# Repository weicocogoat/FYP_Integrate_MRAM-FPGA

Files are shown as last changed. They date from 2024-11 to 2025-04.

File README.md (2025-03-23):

# Integrating Off-Chip rapid non-volatile with RISC-V Core on FPGA
This repository documents my progress of my FYP at NTU, designing an MRAM memory controller and integrating it with the ECS-DOT SoC developed at NTU by the ECS Group.

## Navigation
If you are here from the report, please look into the FYP_Report folder for the relevant files

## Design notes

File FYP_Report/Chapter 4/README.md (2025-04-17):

# Chapter 4 - Hardware Design
Folders will namely contain the Verilog files used. 

## Section 4.1 - SPS Module
- Relevant Folder: SPS_Module
- Top Module: MRAM_Top_Module.v
- Testbench: MRAM_Top_Module_tb.v

## Section 4.2 - SPS with burst functionality
- Relevant Folder: SPS_Burst
- Top Module: Integrate_Top_Module.v
- Testbench: Integrate_Top_Module_tb.v
- Constraint file is for the Tang Nano 9k

## Section 4.3 - SPI-SPS Module
- Relevant Folder: SPI-SPS
- Top Module: SPI_Top_Module.v
- Testbench: SPI_Top_Module_tb.v

## Section 4.4 - SPI Module
- Relevant Folder: SPI_Module
- Top Module: SPI_top_module.v
- Testbench: SPI_Slave_tb.v
- Contraint file is for the Tang Nano 9k

## Section 4.5.1 - Initial I2C Module
- Relevant Folder: I2C_Initial_Design
- Top Module: top_module.v
- Testbench: top_module_tb.v

## Section 4.5.2 - OpenIP Cores I2C Slave
- Relevant Folder: ip-core-communication-controller_i2c_slave/rtl
- Top Module: i2cSlaveTop.v
- Testbench: ip-core-communication-controller_i2c_slave/sim & ip-core-communication-controller_i2c_slave/bench
- Running the testbench requires Icarus Verilog and GTK wave

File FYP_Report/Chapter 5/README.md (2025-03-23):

## Section 5.1 - SPS burst module
- Includes the STM32 C file and .ioc file that is used to test the SPS burst design
- Also includes the PulseView waveforms of the operations performed in the [video](https://youtu.be/q7COcFoSyC0) showcasing SPS burst operations

## Section 5.2 - SPI Module
- Includes the full Gowin IDE files generated for the Simple_SPI and Truncated_SPI implementations
- Includes the RPI Pico files and several PulseView waveforms

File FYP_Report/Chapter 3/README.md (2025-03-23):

# Chapter 3 - Hardware and their relevant software
This README will go over the hardware utilized and the corresponding software used.

## Section 3.2 PCB Designs

### Passive PCB Design
- PCB design 1 files, done in KiCad 8.0
### TangNano-MRAM zip file
- PCB design 2 files, done in KiCad 8.0
- This is the most relevant and up-to-date PCB design that is being used

## Section 3.3 FPGA
- For Zedboard, Vivado and Vitis were used
- For Tang Nano FPGA, the [Gowin IDE](https://www.gowinsemi.com/en/support/download_eda/) was used

## Section 3.4 MCUs
- For STM32, STM32CubeIDE was utilized
- For Raspberry Pi, the Raspberry Pi OS (64-bit) was used
- For ESP32, the Arduino IDE was used
- For Raspberry Pi Pico 2w, Thonny and micropython was used

## Section 3.5 Logic Analyzer
- For the Salae Logic Analyzer, [PulseView](https://sigrok.org/wiki/Downloads) was used

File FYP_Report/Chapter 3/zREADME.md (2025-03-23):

## Passive PCB Design
- PCB design 1 files, done in KiCad

## TangNano-MRAM zip file
- PCB design 2 files, done in KiCad

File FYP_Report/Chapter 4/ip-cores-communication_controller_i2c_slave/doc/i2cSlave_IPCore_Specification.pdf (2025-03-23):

# i2cSlave

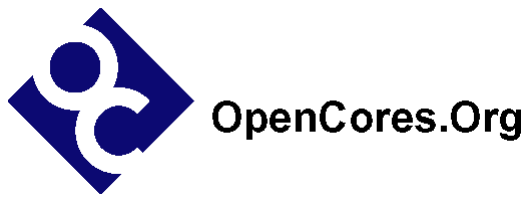
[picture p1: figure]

# Specification

### Author: Steve Fielding sfielding@base2designs.com

### Rev. 1.1 December 17, 2008

OpenCores | 12/17/2008

### Revision History

Rev. | Date | Author | Description
1.0 | 11/07/08 | Sfielding | Created
1.1 | 12/17/08 | Sfielding | Added Aardvark software chapter
www.opencores.org | Rev 1.1 | ii

# Contents

www.opencores.org | Rev 1.1 | iii

1

# Introduction

i2cSlave is a minimalist I2C slave IP core that provides the basic framework for the implementation of custom I2C slave devices. The core provides a means to read and write up to 256 8-byte registers. These registers can be connected to the users custom logic, thus implementing a simple control and status interface.

www.opencores.org | Rev 1.1 | 1 of 14

2

# Architecture

3

# Operation

The core has up 256 registers that can be accessed via I2C. I2C write operations are used to set the register address pointer, and write the register data. I2C reads are used to read the register data. Successive data reads or writes result in data being read or written from incremental register addresses. There is no limit on how much data can be read or written in a single access, but the internal register address pointer will wrap round to 0 once it reaches 255. Note that the address pointer is not initialized at reset, and the address pointer must be set via I2C.
Operation is explained through the use of examples. Examples assume 4 R/W registers at address 0x0, and 4 read only registers at address 0x4, with contents = 0x12345678
Set register address pointer = 0x00:
Byte No. | Data | R/W | Description | Start/Stop | Ack/Nak
1 | 0x78 | W | Device address WR | STA
2 | 0x00 | W | Set register address = 0x00 | STO

Write 4 bytes of data starting at register address 0x00:
Byte No. | Data | R/W | Description | Start/Stop | Ack/Nak
1 | 0x78 | W | Device address WR | STA
2 | 0x00 | W | Set register address = 0x00
3 | 0x89 | W | Write reg[0x00]
4 | 0xab | W | Write reg[0x01]
5 | 0xcd | W | Write reg[0x02]
6 | 0xef | W | Write reg[0x03] | STO

Read 4 bytes of data starting at register address 0x00:
Byte No. | Data | R/W | Description | Start/Stop | Ack/Nak
1 | 0x78 | W | Device address WR | STA

2 | 0x00 | W | Set register address = 0x00 | STO
3 | 0x79 | W | Device address RD | STA
4 | 0x89 | R | Read reg[0x00] | | ACK
5 | 0xab | R | Read reg[0x01] | | ACK
6 | 0xcd | R | Read reg[0x02] | | ACK
7 | 0xef | R | Read reg[0x03] | | NAK

Read 4 bytes of data starting at register address 0x04:
Byte No. | Data | R/W | Description | Start/Stop | Ack/Nak
1 | 0x78 | W | Device address WR | STA
2 | 0x04 | W | Set register address = 0x04 | STO
3 | 0x79 | W | Device address RD | STA
4 | 0x12 | R | Read reg[0x04] | | ACK
5 | 0x34 | R | Read reg[0x05] | | ACK
6 | 0x56 | R | Read reg[0x06] | | ACK
7 | 0x78 | R | Read reg[0x07] | | NAK

## Modify the existing files

You will need to modify i2cSlave to suit your individual application. Specifically you will need to modify;
i2cSlave_define.v
Change I2C_ADDRESS to your I2C device address.
Change CLK_FREQ to match your system clock frequency.
registerInterface.v
Modify the input/output ports and the read and write processes to implement your own register interface.
i2cSlave.v
Modify the input/output ports and the instantiation of registerInterface to connect the modified registerInterface ports to the i2cSlave ports. The tri-state buffer is included here for convenience, but you may wish to remove it, and implement the tri-state buffer in your top level module. Note that only sdaIn and sdaOut are defined. If you wish for a more conventional tri-state interface, you can implement the following;
assign sda_i = sdaIn;

assign sda_o = 1'b0;
assign sda_oe_n = sdaOut;

## Add your own custom logic

Now you can include i2cSlave in your own top level module that connects the registers to your own custom logic, and connects sda and scl to your top level ports.

4.

# Aardvark I2C Test Software

The TotalPhase Aardvark I2C Host Adapter (http://www.totalphase.com/products/aardvark_i2cspi/) provides a great way to test the i2cSlave core in hardware. The Aardvark connects to the target via 3 wires (SCL, SDA, GND), and connects to a PC via USB. You can use the TotalPhase Aardvark GUI to read and write to the core.

Aardvark GUI
Connect the Aardvark to your target hardware and a PC. On the PC open the Aardvark GUI, select the Aardvark device, then select batch mode. Click the 'Load' button, and browse to sw\aardvark_xml\readWriteTest.xml and click 'Open'. Now, click on the 'Execute' button.
You should see something similar to the following:

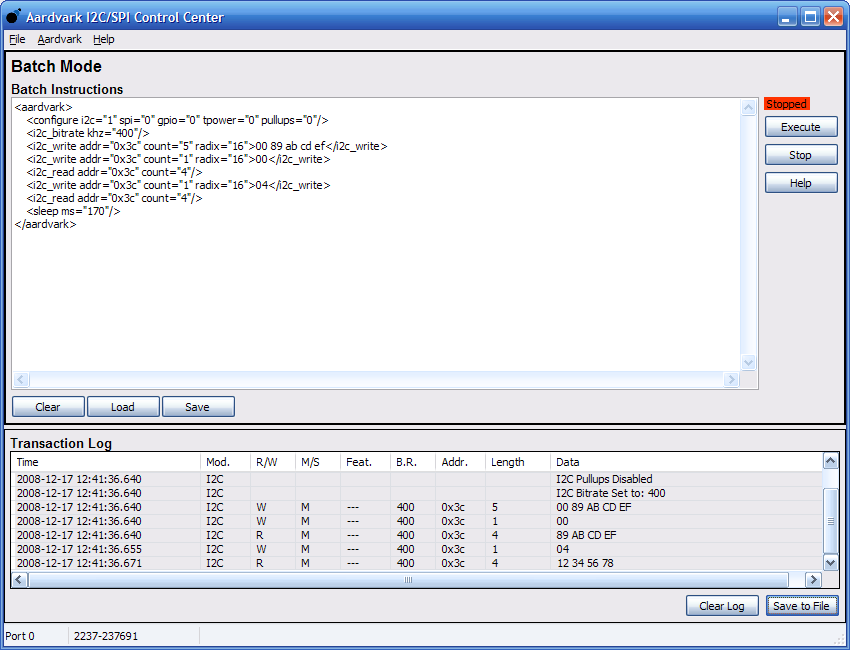
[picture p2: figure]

Aardvark C/C++ MinGW
Windows gcc-mingw32:
1) Install GCC MinGW32.
From Base2Designs CD-ROM tools\MinGW_MSYS
Or the the latest version can be downloaded from the MinGW website: http://www.mingw.org/
2) Install MSYS
From Base2Designs CD-ROM tools\MinGW_MSYS
Or the latest version can be downloaded from the MinGW website: http://www.mingw.org/
3) From i2cSlave/sw/aardvark_c type 'make' at the MSYS command line
4) The executable is in i2cSlave/sw/aardvark_c/_output/

5

# Clocks

Name | Source | Rates (MHz) | Remarks | Description
Max | Min | Res
clk | Input Pad | Limited by hardware | TBD. Only tested at 48MHz | - Duty cycle | 50/50. | System clock.

Table 1: List of clocks

6

# IO Ports

Port | Width | Direction | Description
clk | 1 | input | Clock. If you change this clock from 48MHz you may need to alter some constants in the i2cSlave_define.v file
rst | 1 | input | 1 = reset. Synchronous to clk. Resets all logic.
sda | 8 | inout | I2C SDA
scl | 8 | inout | I2C SCL
MyReg[3:0] | 8 | output | I2C accessible output registers. Modify to implement your own custom outputs
MyReg[7:4] | 8 | input | I2C accessible input registers. Modify to implement your own custom inputs

Table 2: List of IO ports

7

# Resource Utilization

Target Device | Logic Cells / Macrocells | Memory bits
EPM7256 (256 macrocell CPLD) | 143 macrocells | 0
EP2C20 | 218 logic cells | 0

Table 3 Resource utilization for Altera CycloneEP2C20, and EPM7256

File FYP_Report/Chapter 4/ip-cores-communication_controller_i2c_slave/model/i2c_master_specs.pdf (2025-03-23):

I

2

# C-Master Core Specification

# Author: Richard Herveille

### rherveille@opencores.org

### Rev. 0.9 July 3, 2003

## This page has been intentionally left blank

### Revision History

Rev. | Date | Author | Description
0.1 | 17/02/01 | Richard Herveille | First draft release
0.2 | 01/03/01 | Richard Herveille | Some cleaning up throughout the document Added ‘Programming Examples’ section
0.3 | | Richard Herveille | Added some comments after core-changes - added BUSY bit (status register) - changed I2C IO for ASIC support - added comment for FGPA IO
0.4 | 10/19/01 | Richard Herveille | Changed core’s databus size to 8bit. Changed documentation to reflect changes. Changed port names to new naming convention.
0.5 | 18/02/02 | Richard Herveille | Changed table headers. Added OpenCores logo.
0.5a | 05/02/02 | Richard Herveille | Reviewed entire document.
0.6 | 21/03/02 | Richard Herveille | Added Appendix A, Synthesis Results
0.7 | 25/06/02 | Richard Herveille | Changed Prescale Register formula
0.8 | 30/12/02 | Richard Herveille | Added Multi-Master capabilities. New timing diagrams.
0.9 | 03/07/03 | Richard Herveille | Changed ‘0x5C’ to ‘0xAC’ in Example1. Changed ‘RW’ to ‘W’ in Command Register. Changed ‘RW’ to ‘W’ in Transmit Register.

OpenCores | I²
C-Master core | 7/3/2003
www.opencores.org | Rev 0.8 Preliminary | 1 of 15

1

# Introduction

I

2
C is a two-wire, bi-directional serial bus that provides a simple and efficient method of data exchange between devices. It is most suitable for applications requiring occasional communication over a short distance between many devices. The I²
C standard is a true
multi-master bus including collision detection and arbitration that prevents data corruption if two or more masters attempt to control the bus simultaneously.

The interface defines 3 transmission speeds:
- Normal: 100Kbps
- Fast: 400Kbps
- High speed: 3.5Mbps

Only 100Kbps and 400Kbps modes are supported directly. For High speed special IOs are needed. If these IOs are available and used, then High speed is also supported.

## FEATURES

- Compatible with Philips I²
C standard
- Multi Master Operation
- Software programmable clock frequency
- Clock Stretching and Wait state generation
- Software programmable acknowledge bit
- Interrupt or bit-polling driven byte-by-byte data-transfers
- Arbitration lost interrupt, with automatic transfer cancelation
- Start/Stop/Repeated Start/Acknowledge generation
- Start/Stop/Repeated Start detection
- Bus busy detection
- Supports 7 and 10bit addressing mode
- Operates from a wide range of input clock frequencies
- Static synchronous design
- Fully synthesizable

2

# IO ports

## 2.1 Core Parameters

Parameter | Type | Default | Description
ARST_LVL | Bit | 1’b0 | Asynchronous reset level

### 2.1.1 ARST_LVL

The asynchronous reset level can be set to either active high (1’b1) or active low (1’b0).

## 2.2 WISHBONE interface signals

Port | Width | Direction | Description
wb_clk_i | 1 | Input | Master clock
wb_rst_i | 1 | Input | Synchronous reset, active high
arst_i | 1 | Input | Asynchronous reset
wb_adr_i | 3 | Input | Lower address bits
wb_dat_i | 8 | Input | Data towards the core
wb_dat_o | 8 | Output | Data from the core
wb_we_i | 1 | Input | Write enable input
wb_stb_i | 1 | Input | Strobe signal/Core select input
wb_cyc_i | 1 | Input | Valid bus cycle input
wb_ack_o | 1 | Output | Bus cycle acknowledge output
wb_inta_o | 1 | Output | Interrupt signal output

The core features a WISHBONE RevB.3 compliant WISHBONE Classic interface. All output signals are registered. Each access takes 2 clock cycles.
arst_i is not a WISHBONE compatible signal. It is provided for FPGA implementations. Using [arst_i] instead of [wb_rst_i] can result in lower cell-usage and higher performance, because most FPGAs provide a dedicated asynchronous reset path. Use either [arst_i] or [wb_rst_i], tie the other to a negated state.

## 2.3 External connections

Port | Width | Direction | Description
scl_pad_i | 1 | Input | Serial Clock line input
scl_pad_o | 1 | Output | Serial Clock line output
scl_pad_oe | 1 | Output | Serial Clock line output enable
sda_pad_i | 1 | Input | Serial Data line input
sda_pad_o | 1 | Output | Serial Data line output
sda_pad_oe | 1 | Output | Serial Data line output enable

The I²
C interface uses a serial data line (SDA) and a serial clock line (SCL) for data transfers. All devices connected to these two signals must have open drain or open collector outputs. Both lines must be pulled-up to VCC by external resistors.

The tri-state buffers for the SCL and SDA lines must be added at a higher hierarchical level. Connections should be made according to the following figure:

For FPGA designs the compiler can automatically insert these buffers using the following VHDL code:

scl <= scl_pad_o when (scl_padoen_oe = ‘0’) else ‘Z’;
sda <= sda_pad_o when (sda_padoen_oe = ‘0’) else ‘Z’;
scl_pad_i <= scl;
scl_pad_i <= sda;

Verilog code:

assign scl = scl_padoen_oe ? 1’bz : scl_pad_o; assign sda = sda_padoen_oe ? 1’bz: sda_pad_o; assign scl_pad_i = scl;
assign sda_pad_i = sda;

scl_pad_i

scl_pad_o

scl_padoen_o
sda_pad_i

sda_pad_o

sda_padoen_o

SCL

SDA

3

# Registers

## 3.1 Registers list

Name | Address | Width | Access | Description
PRERlo | 0x00 | 8 | RW | Clock Prescale register lo-byte
PRERhi | 0x01 | 8 | RW | Clock Prescale register hi-byte
CTR | 0x02 | 8 | RW | Control register
TXR | 0x03 | 8 | W | Transmit register
RXR | 0x03 | 8 | R | Receive register
CR | 0x04 | 8 | W | Command register
SR | 0x04 | 8 | R | Status register

## 3.2 Register description

### 3.2.1 Prescale Register

This register is used to prescale the SCL clock line. Due to the structure of the I² C
interface, the core uses a 5*SCL clock internally. The prescale register must be programmed to this 5*SCL frequency (minus 1). Change the value of the prescale register only when the ‘EN’ bit is cleared.

Example: wb_clk_i = 32MHz, desired SCL = 100KHz
1 | 63 ( | ) | 3 ( | ) 5 100
32 | dec | F hex
KHz
MHz prescale | − = | = ∗ =

Reset value: 0xFFFF

### 3.2.2 Control register

Bit # | Access | Description
7 | RW | EN, I² C core enable bit. When set to ‘1’, the core is enabled. When set to ‘0’, the core is disabled.
6 | RW | IEN, I² C core interrupt enable bit. When set to ‘1’, interrupt is enabled. When set to ‘0’, interrupt is disabled.
5:0 | RW | Reserved
Reset Value: 0x00

The core responds to new commands only when the ‘EN’ bit is set. Pending commands are finished. Clear the ‘EN’ bit only when no transfer is in progress, i.e. after a STOP command, or when the command register has the STO bit set. When halted during a transfer, the core can hang the I²
C bus.

### 3.2.3 Transmit register

Bit # | Access | Description
7:1 | W | Next byte to transmit via I² C
0 | W | In case of a data transfer this bit represent the data’s LSB. In case of a slave address transfer this bit represents the RW bit. ‘1’ = reading from slave ‘0’ = writing to slave

Reset value: 0x00

### 3.2.4 Receive register

Bit # | Access | Description
7:0 | R | Last byte received via I² C
Reset value: 0x00

### 3.2.5 Command register

Bit # | Access | Description
7 | W | STA, generate (repeated) start condition
6 | W | STO, generate stop condition
5 | W | RD, read from slave
4 | W | WR, write to slave
3 | W | ACK, when a receiver, sent ACK (ACK = ‘0’) or NACK (ACK = ‘1’)
2:1 | W | Reserved
0 | W | IACK, Interrupt acknowledge. When set, clears a pending interrupt.
Reset Value: 0x00

The STA, STO, RD, WR, and IACK bits are cleared automatically. These bits are always read as zeros.

### 3.2.6 Status register

Bit # | Access | Description
7 | R | RxACK, Received acknowledge from slave. This flag represents acknowledge from the addressed slave. ‘1’ = No acknowledge received ‘0’ = Acknowledge received
6 | R | Busy, I² C bus busy ‘1’ after START signal detected ‘0’ after STOP signal detected
5 | R | AL, Arbitration lost This bit is set when the core lost arbitration. Arbitration is lost when: • a STOP signal is detected, but non requested • The master drives SDA high, but SDA is low. See bus-arbitration section for more information.
4:2 | R | Reserved
1 | R | TIP, Transfer in progress. ‘1’ when transferring data ‘0’ when transfer complete
0 | R | IF, Interrupt Flag. This bit is set when an interrupt is pending, which will cause a processor interrupt request if the IEN bit is set. The Interrupt Flag is set when: • one byte transfer has been completed • arbitration is lost

Reset Value: 0x00

Please note that all reserved bits are read as zeros. To ensure forward compatibility, they should be written as zeros.

4

# Operation

## 4.1 System Configuration

The I²
C system uses a serial data line (SDA) and a serial clock line (SCL) for data transfers. All devices connected to these two signals must have open drain or open collector outputs. The logic AND function is exercised on both lines with external pull-up resistors.

Data is transferred between a Master and a Slave synchronously to SCL on the SDA line on a byte-by-byte basis. Each data byte is 8 bits long. There is one SCL clock pulse for each data bit with the MSB being transmitted first. An acknowledge bit follows each transferred byte. Each bit is sampled during the high period of SCL; therefore, the SDA line may be changed only during the low period of SCL and must be held stable during the high period of SCL. A transition on the SDA line while SCL is high is interpreted as a command (see START and STOP signals).

## 4.2 I² C Protocol

Normally, a standard communication consists of four parts:
1) START signal generation
2) Slave address transfer
3) Data transfer
4) STOP signal generation
S | A7 | A6 | A5 | A4 | A3 | A2 | A1 | RW ACK | D7 | D6 | D5 | D4 | D3 | D2 | D1 | D0 NACK | P

SCL

SDA

1 | 2 | 3 | 4 | 5 | 6 | 7 | 8 | 9
MSB | LSB
1 | 2 | 3 | 4 | 5 | 6 | 7 | 8 | 9
MSB | LSB

### 4.2.1 START signal

When the bus is free/idle, meaning no master device is engaging the bus (both SCL and SDA lines are high), a master can initiate a transfer by sending a START signal. A START signal, usually referred to as the S-bit, is defined as a high-to-low transition of SDA while SCL is high. The START signal denotes the beginning of a new data transfer. A Repeated START is a START signal without first generating a STOP signal. The master uses this method to communicate with another slave or the same slave in a different transfer direction (e.g. from writing to a device to reading from a device) without releasing the bus.

The core generates a START signal when the STA-bit in the Command Register is set and the RD or WR bits are set. Depending on the current status of the SCL line, a START or Repeated START is generated.

### 4.2.2 Slave Address Transfer

The first byte of data transferred by the master immediately after the START signal is the slave address. This is a seven-bits calling address followed by a RW bit. The RW bit signals the slave the data transfer direction. No two slaves in the system can have the same address. Only the slave with an address that matches the one transmitted by the master will respond by returning an acknowledge bit by pulling the SDA low at the 9th SCL clock cycle.

Note: The core supports 10bit slave addresses by generating two address transfers. See the Philips I²
C specifications for more details.

The core treats a Slave Address Transfer as any other write action. Store the slave device’s address in the Transmit Register and set the WR bit. The core will then transfer the slave address on the bus.

### 4.2.3 Data Transfer

Once successful slave addressing has been achieved, the data transfer can proceed on a byte-by-byte basis in the direction specified by the RW bit sent by the master. Each transferred byte is followed by an acknowledge bit on the 9th SCL clock cycle. If the slave signals a No Acknowledge, the master can generate a STOP signal to abort the data transfer or generate a Repeated START signal and start a new transfer cycle.

If the master, as the receiving device, does not acknowledge the slave, the slave releases the SDA line for the master to generate a STOP or Repeated START signal.

To write data to a slave, store the data to be transmitted in the Transmit Register and set the WR bit. To read data from a slave, set the RD bit. During a transfer the core set the TIP flag, indicating that a Transfer is In Progress. When the transfer is done the TIP flag is reset, the IF flag set and, when enabled, an interrupt generated. The Receive Register contains valid data after the IF flag has been set. The user may issue a new write or read command when the TIP flag is reset.

### 4.2.4 STOP signal

The master can terminate the communication by generating a STOP signal. A STOP signal, usually referred to as the P-bit, is defined as a low-to-high transition of SDA while SCL is at logical ‘1’.

## 4.3 Arbitration Procedure

### 4.3.1 Clock Synchronization

The I²
C bus is a true multimaster bus that allows more than one master to be connected on it. If two or more masters simultaneously try to control the bus, a clock synchronization procedure determines the bus clock. Because of the wired-AND connection of the I²
C signals a high to low transition affects all devices connected to the bus. Therefore a high to low transition on the SCL line causes all concerned devices to count off their low period. Once a device clock has gone low it will hold the SCL line in that state until the clock high state is reached. Due to the wired-AND connection the SCL line will therefore be held low by the device with the longest low period, and held high by the device with the shortest high period.

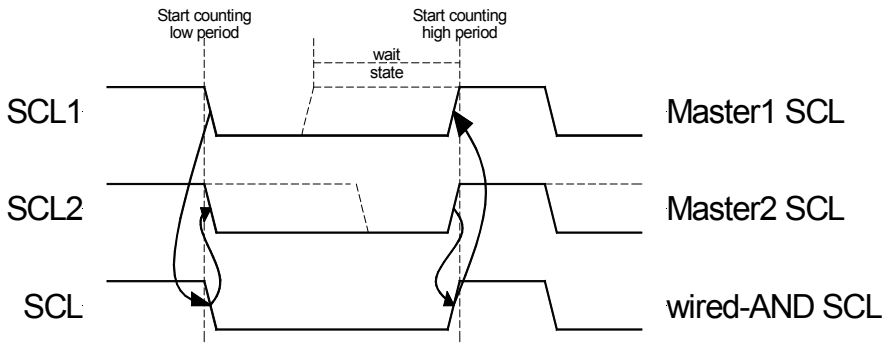
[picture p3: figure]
Start counting low period; wait state; Start counting high period; SCL1; SCL2; SCL; Master1 SCL; Master2 SCL; wired-AND SCL

### 4.3.2 Clock Stretching

Slave devices can use the clock synchronization mechanism to slow down the transfer bit rate. After the master has driven SCL low, the slave can drive SCL low for the required period and then release it. If the slave’s SCL low period is greater than the master’s SCL low period, the resulting SCL bus signal low period is stretched, thus inserting wait-states.

5

# Architecture

The I2C core is built around four primary blocks; the Clock Generator, the Byte Command Controller, the Bit Command Controller and the DataIO Shift Register. All other blocks are used for interfacing or for storing temporary values.

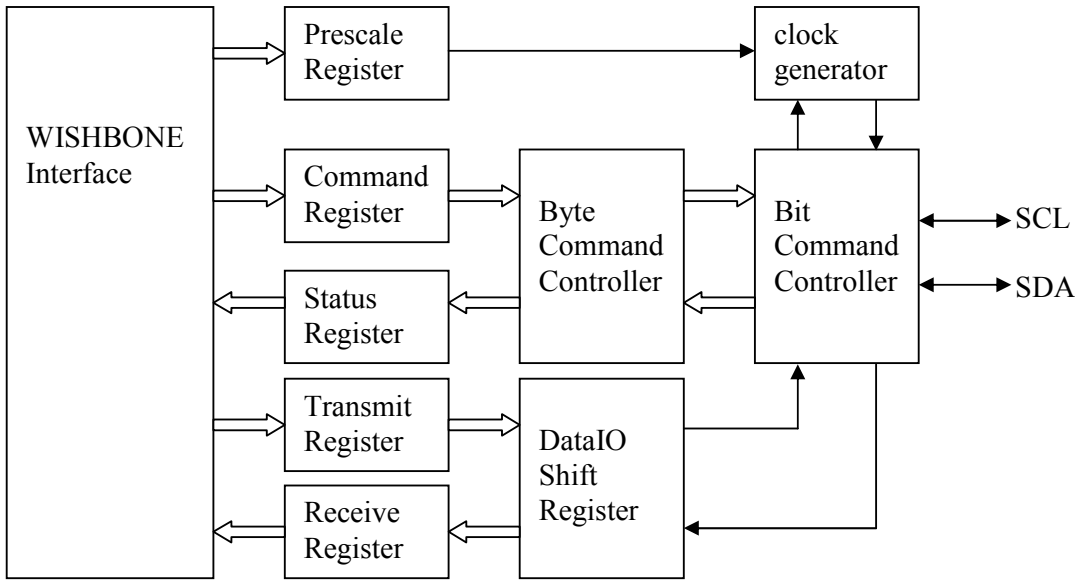
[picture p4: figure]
SCL; SDA; Prescale Register; clock generator; Command Register; Status Register; Byte Command Controller; Bit Command Controller; WISHBONE Interface; Transmit Register; Receive Register; DataIO Shift Register

## 5.1 Clock Generator

The Clock Generator generates an internal 4*Fscl clock enable signal that triggers all synchronous elements in the Bit Command Controller. It also handles clock stretching needed by some slaves.

## 5.2 Byte Command Controller

The Byte Command Controller handles I2C traffic at the byte level. It takes data from the Command Register and translates it into sequences based on the transmission of a single byte. By setting the START, STOP, and READ bit in the Command Register, for example, the Byte Command Controller generates a sequence that results in the

Fig. 5.1 Internal structure I2C Master Core

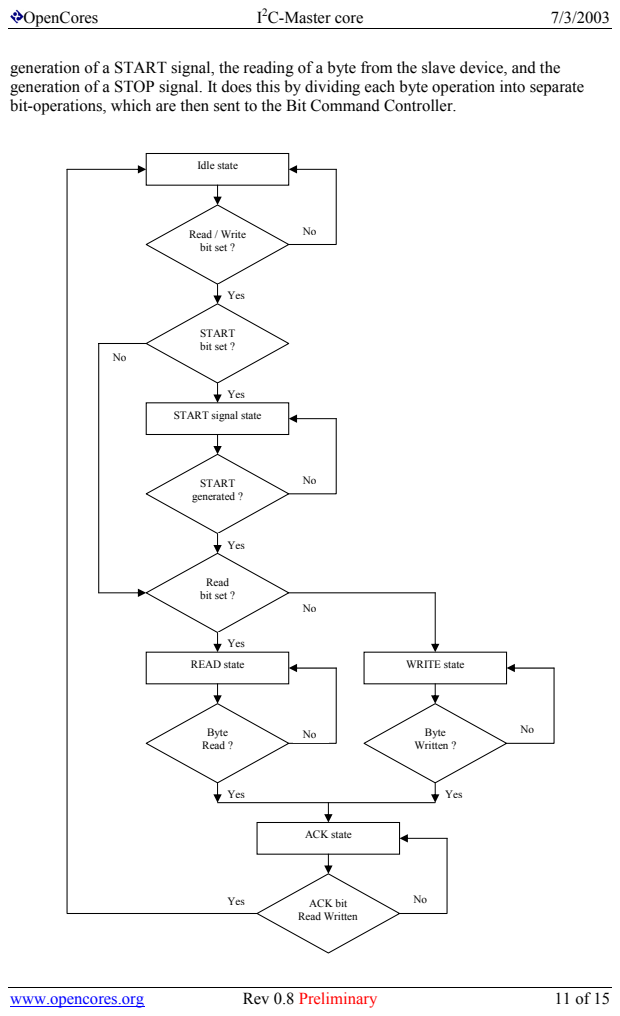
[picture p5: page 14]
Idle state; Read / Write bit set ?; Yes; START bit set ?; Read bit set ?; READ state; Byte Read ?; ACK state; WRITE state; Byte Written ?; ACK bit Read Written

generation of a START signal, the reading of a byte from the slave device, and the
generation of a STOP signal. It does this by dividing each byte operation into separate
bit-operations, which are then sent to the Bit Command Controller.

START signal state

START generated ?

## 5.3 Bit Command Controller

The Bit Command Controller handles the actual transmission of data and the generation of the specific levels for START, Repeated START, and STOP signals by controlling the SCL and SDA lines. The Byte Command Controller tells the Bit Command Controller which operation has to be performed. For a single byte read, the Bit Command Controller receives 8 separate read commands. Each bit-operation is divided into 5 pieces (idle and A, B, C, and D), except for a STOP operation which is divided into 4 pieces (idle and A, B, and C).

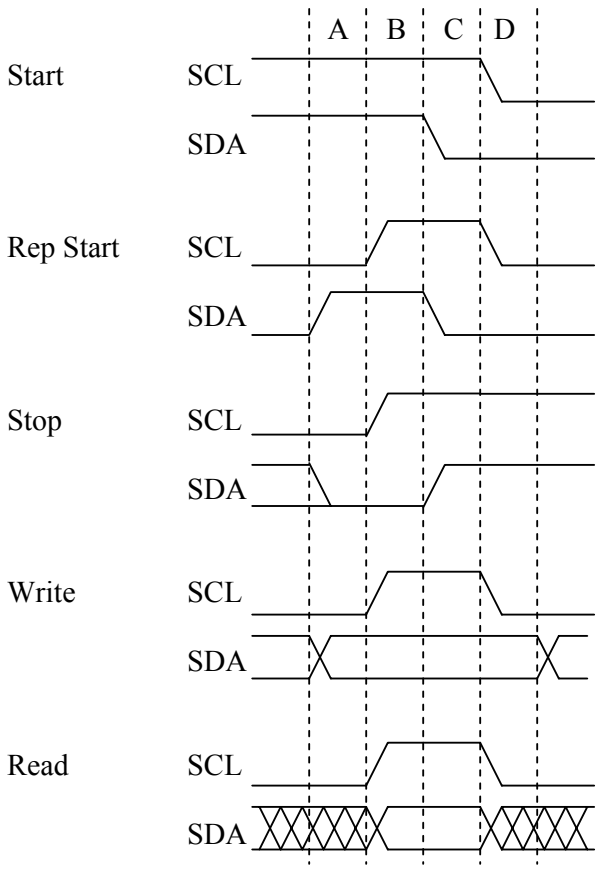
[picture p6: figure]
Start; SCL; SDA; Rep Start; Stop; Write; Read

## 5.4 DataIO Shift Register

The DataIO Shift Register contains the data associated with the current transfer. During a read action, data is shifted in from the SDA line. After a byte has been read the contents are copied into the Receive Register. During a write action, the Transmit Register’s contents are copied into the DataIO Shift Register and are then transmitted onto the SDA line.

6

# Programming examples

## Example 1

Write 1 byte of data to a slave.

Slave address = 0x51 (b”1010001”) Data to write = 0xAC

I2C Sequence:
1) generate start command
2) write slave address + write bit
3) receive acknowledge from slave
4) write data
5) receive acknowledge from slave
6) generate stop command

Commands:
1) write 0xA2 (address + write bit) to Transmit Register, set STA bit, set WR bit. -- wait for interrupt or TIP flag to negate --
2) read RxACK bit from Status Register, should be ‘0’.
write 0xAC to Transmit register, set STO bit, set WR bit.
-- wait for interrupt or TIP flag to negate --
3) read RxACK bit from Status Register, should be ‘0’.

Please note that the time for the Interrupt Service Routine is not shown here. It is assumed that the ISR is much faster then the I²
C cycle time, and therefore not visible.

## Example 2

Read a byte of data from an I2C memory device.

Slave address = 0x4E
Memory location to read from = 0x20

I2C sequence:
1) generate start signal
2) write slave address + write bit
3) receive acknowledge from slave
4) write memory location
5) receive acknowledge from slave
6) generate repeated start signal
7) write slave address + read bit
8) receive acknowledge from slave
9) read byte from slave
10) write no acknowledge (NACK) to slave, indicating end of transfer
11) generate stop signal

Commands:
1) write 0x9C (address + write bit) to Transmit Register, set STA bit, set WR bit. -- wait for interrupt or TIP flag to negate --
2) read RxACK bit from Status Register, should be ‘0’.
write 0x20 to Transmit register, set WR bit.
-- wait for interrupt or TIP flag to negate --
3) read RxACK bit from Status Register, should be ‘0’.
write 0x9D (address + read bit) to Transmit Register, set STA bit, set WR bit. -- wait for interrupt or TIP flag to negate --
4) set RD bit, set ACK to ‘1’ (NACK), set STO bit

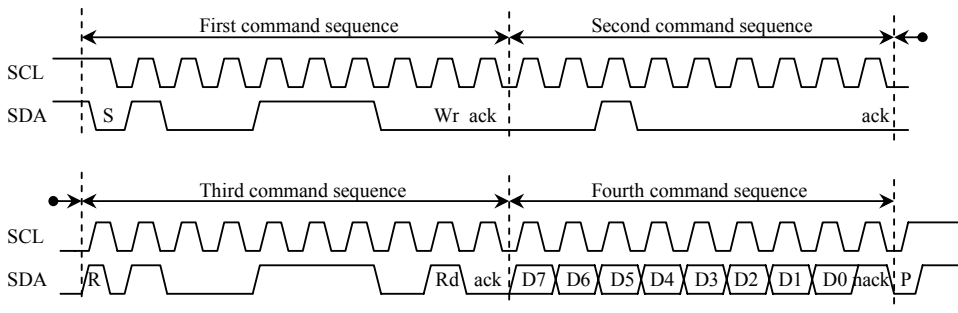
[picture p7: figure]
First command sequence; Second command sequence; SDA; Wr ack; ack; SCL; Third command sequence; Fourth command sequence

Please note that the time for the Interrupt Service Routine is not shown here. It is assumed that the ISR is much faster then the I²
C cycle time, and therefore not visible.
SDA | R | Rd ack | D7 D6 D5 D4 D3 D2 D1 D0 nack | P

# Appendix A

# Synthesis results

Synthesis tool: Synplify Pro

Technology | Device | Speed grade | Fmax | Resource usage
ACTEL | A54SX16ATQ100 | std | 58MHz | Modules: 352
Altera | EP10K50ETC144 | -3 | 82MHz | LCs: 294
| EP20K30ETC144 | -3 | 74MHz | ATOMS: 257
Xilinx | 2s15CS144 | -5 | 82MHz | LUTs: 229
| XCV50ECS144 | -8 | 118MHz | LUTs: 230

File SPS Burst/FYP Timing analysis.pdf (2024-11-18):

# Timing analysis

## Integrated Overview of Controller

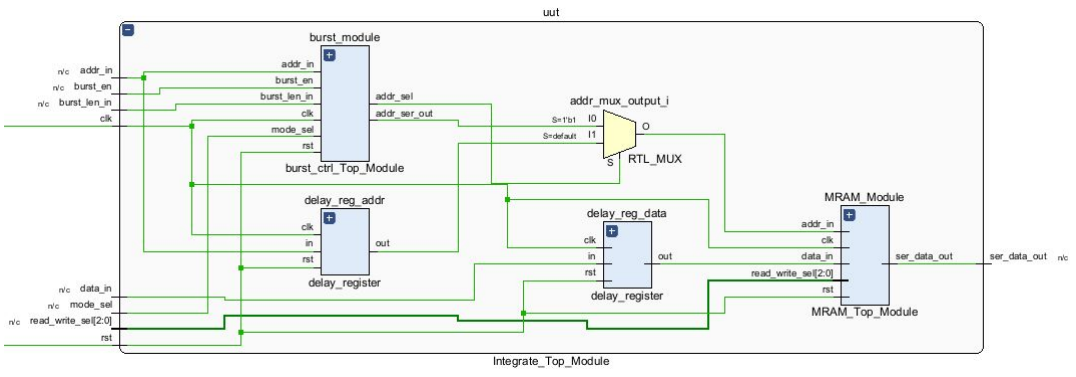
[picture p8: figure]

## During Single Transfer / First loop of Burst Transfer

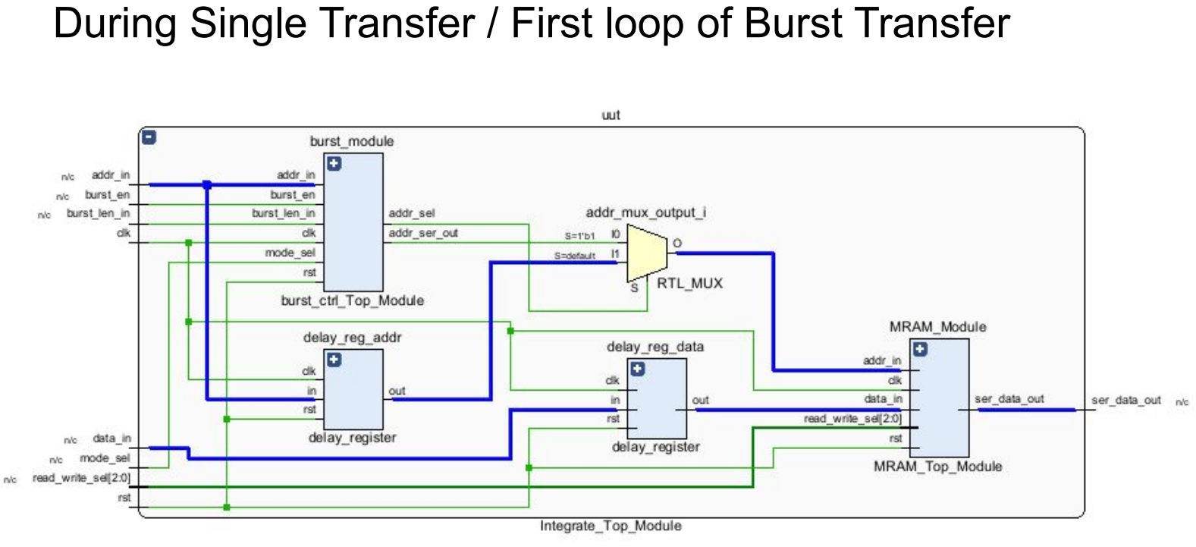
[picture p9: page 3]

## During Burst Transfer

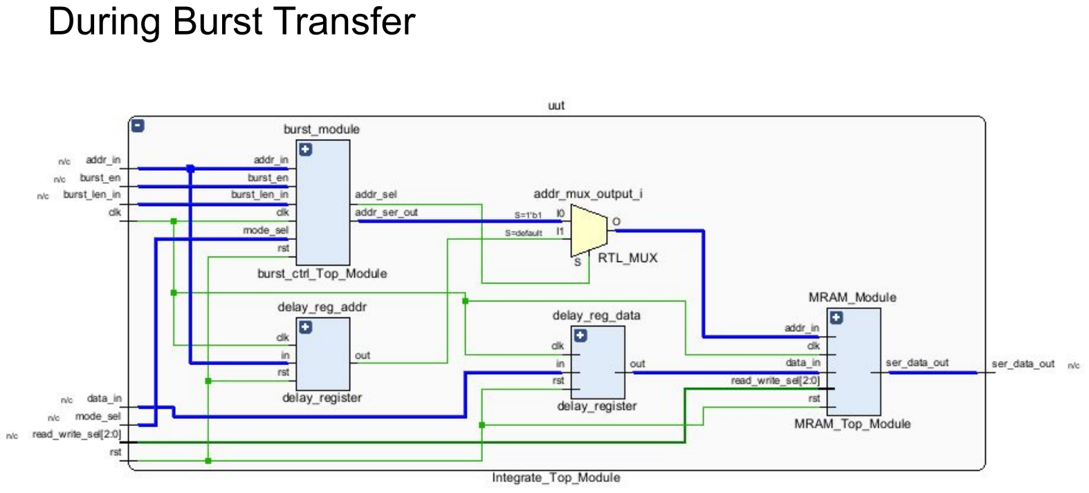
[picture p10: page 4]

## Burst Module

If Single Transfer is selected, don’t do anything.

Done through setting the mux to 0.

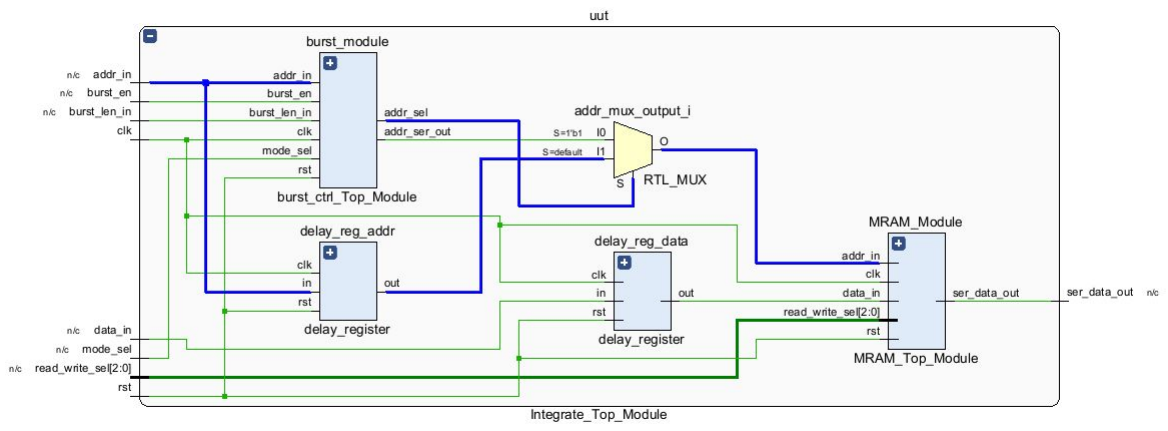
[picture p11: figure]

## Burst Module - Burst len

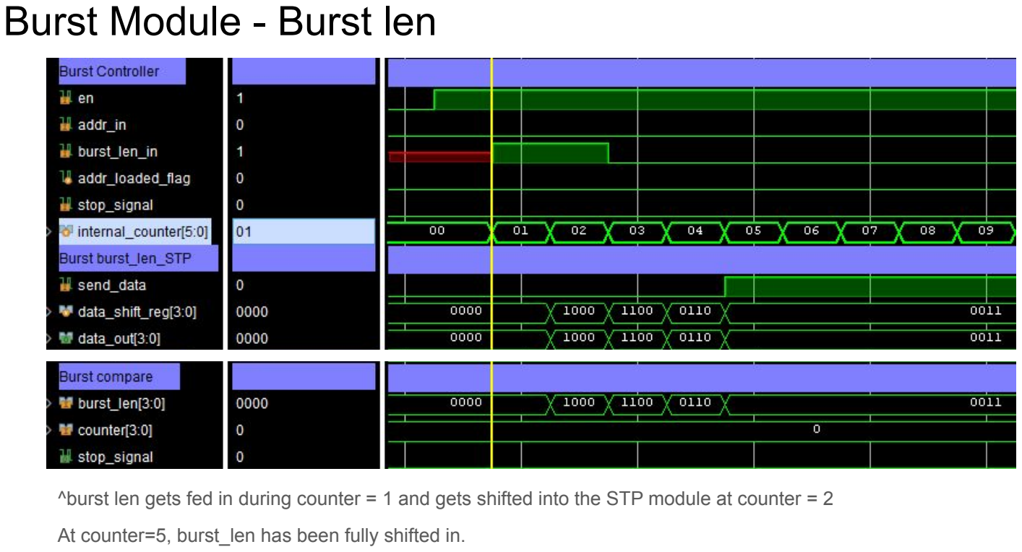
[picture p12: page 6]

^burst len gets fed in during counter = 1 and gets shifted into the STP module at counter = 2

At counter=5, burst_len has been fully shifted in.

## Burst Module - Initial addr

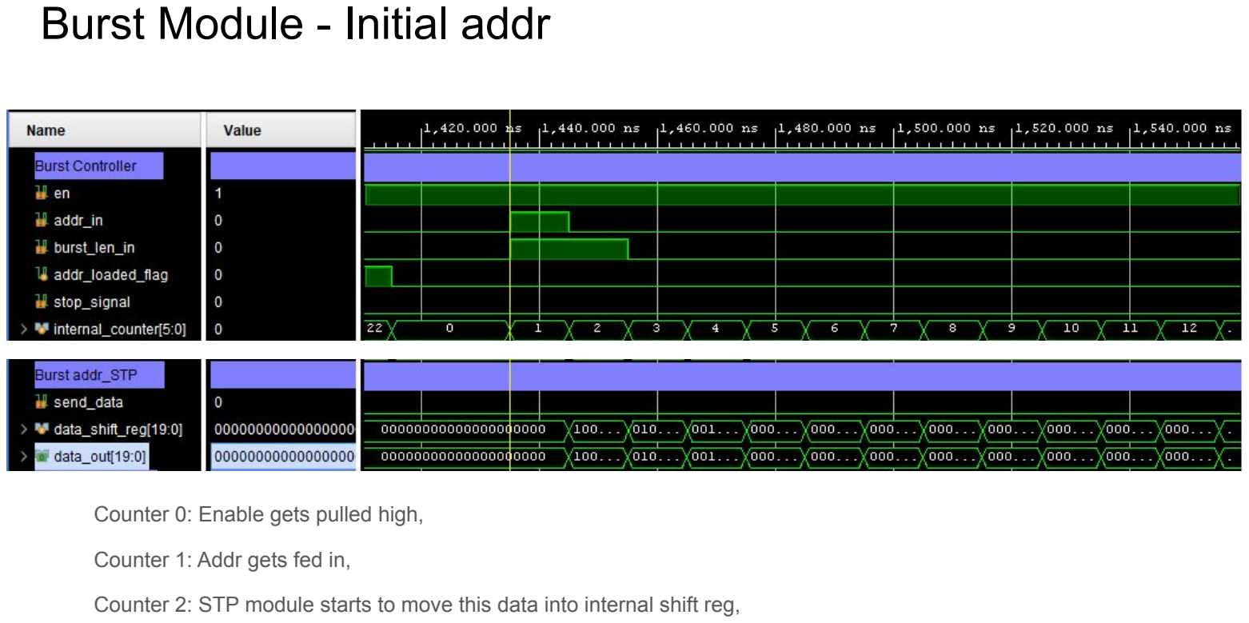
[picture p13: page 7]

Counter 0: Enable gets pulled high,

Counter 1: Addr gets fed in,

Counter 2: STP module starts to move this data into internal shift reg,

## Burst Module - Initial addr

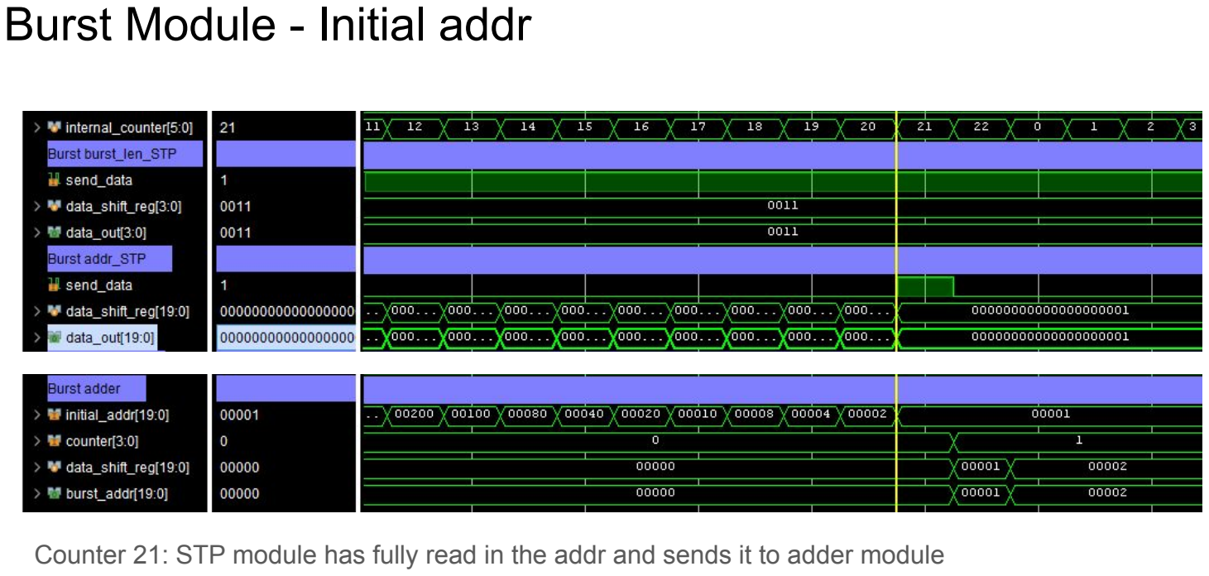
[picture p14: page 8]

Counter 21: STP module has fully read in the addr and sends it to adder module

## Burst Module - Initial addr

After initial addr is loaded, set the loaded flag and addr_sel(mux control)

Addr read for the STP/PTS module starts when counter = 2

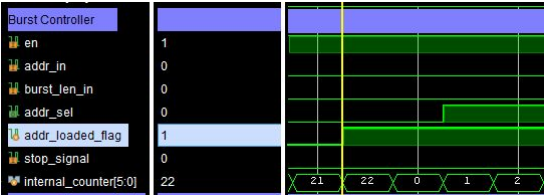
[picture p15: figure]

## Burst Module - Adder

Takes initial addr and counter module’s value and adds them tgt

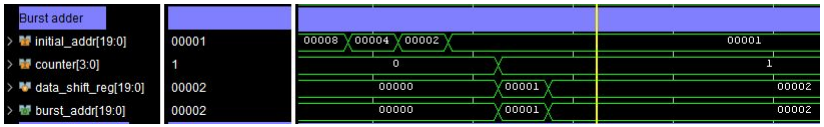
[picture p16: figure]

Counter 22: Initial addr and counter are both available in the adder module

Counter 0 of next loop: Adds initial address and counter value together

## Burst Module - compare module

Cycle 22: When compare module detects that the counter value exceeds the burst len, assert stop signal to the burst control to stop sending address serially

## Burst Module - address PTS module

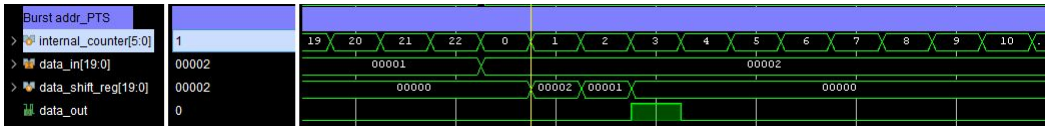
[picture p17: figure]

Counter 1: Next address to be accessed is loaded into the internal shift register

Counter 2: Starts to output the address serially. Address to be output here is 2 (from LSB to MSB)
- Counter 2: output bit 0
- Counter 3: output bit 1
- Counter 4 onwards: output bit 0
- Overall: 20’b0000_0000_0000_0000_0010

## MRAM STP/PTS module -

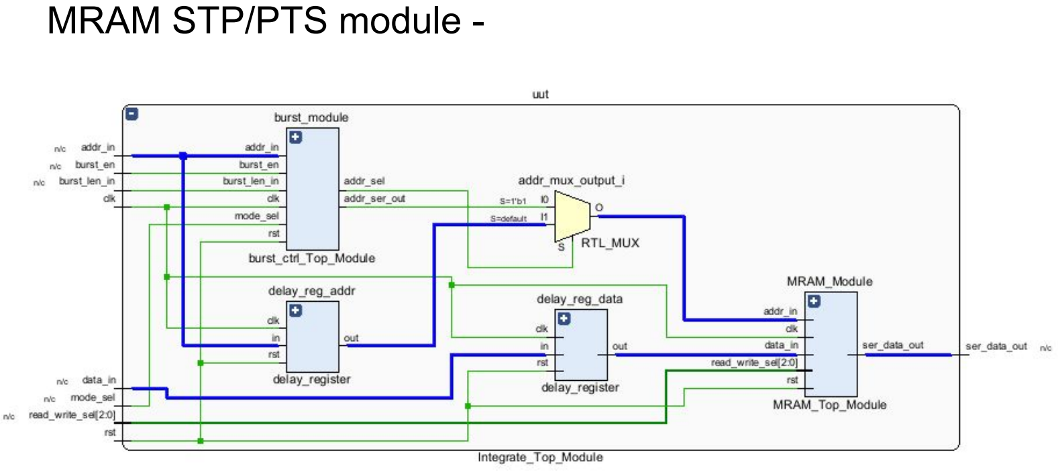
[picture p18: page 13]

## MRAM STP/PTS module - data/addr STP module (write op)

At counter = 2, data gets read and takes 1 cycle to be shifted into the internal shift register

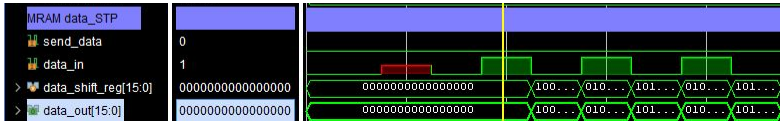
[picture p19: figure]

## MRAM STP/PTS module - data/addr STP module (write op)

At counter = 18, data is fully in the internal shift register.

At counter = 22, addr is fully in the internal shift register.

Can be sent to the MRAM alongside the control signals

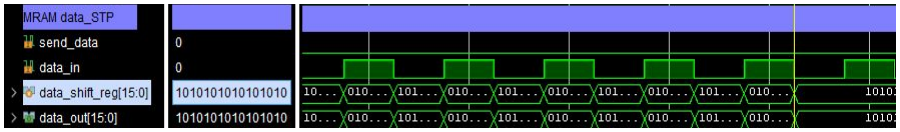
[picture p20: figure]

## MRAM STP/PTS module - addr STP module (write op)

At counter = 22, signals are asserted to write to the MRAM

At counter = 0 of the next cycle, it is in the MRAM

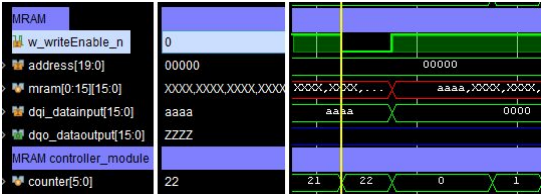
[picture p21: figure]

## MRAM STP/PTS module - Read operation

Data is read out in the next loop after address is provided

Addr = 0; data in address 0 is 5555h, 0101_0101_0101_0101b. Data is output from LSB to MSB

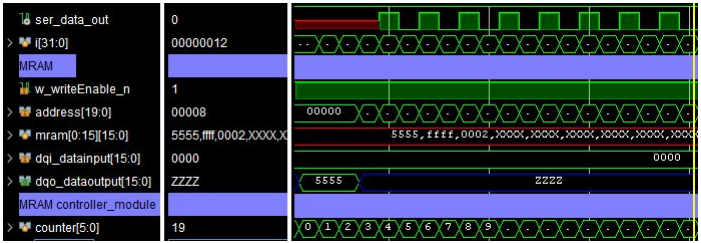
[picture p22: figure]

## Testbench - burst read example

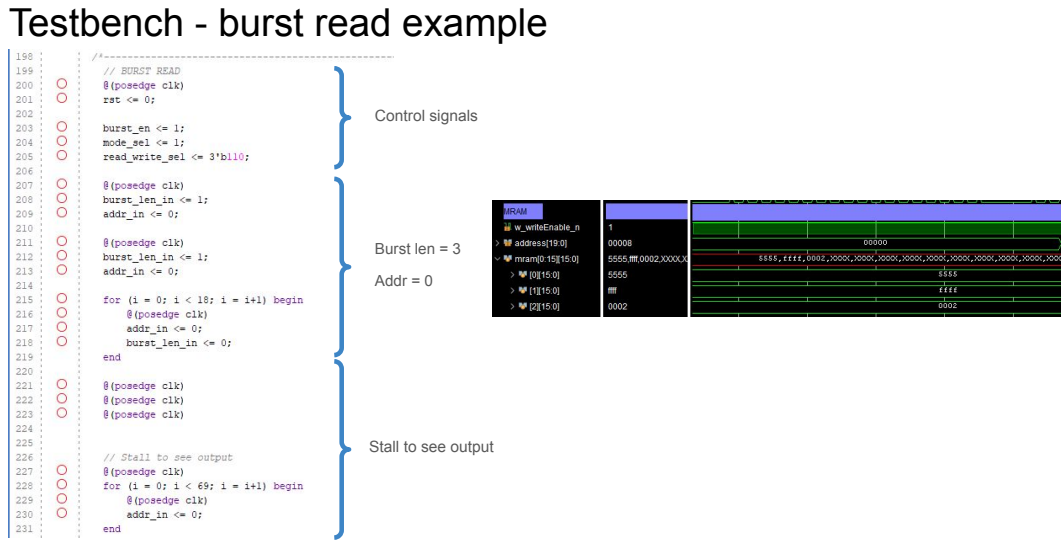
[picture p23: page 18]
Burst len = 3; Addr = 0; Control signals

Stall to see output

## Testbench - burst read example

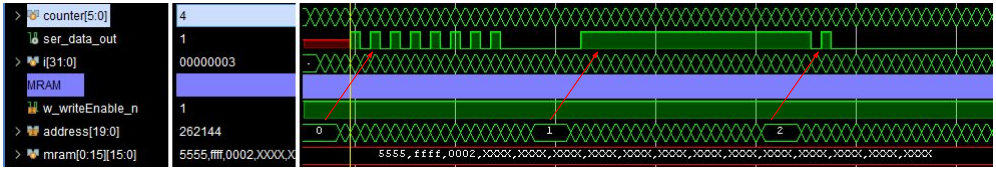
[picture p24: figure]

## Integrated module summary

1 loop consists of 23 cycles (0-22)

Writing:

- Takes 23 cycles

Reading:

- Takes 23 cycles to provide address
- Data is output on the next loop, cycle 4 to 19

## MRAM STP/PTS module standalone

Data is being shifted into the STP module’s shift register during counter 1 instead of counter 2 as opposed to the integrated module


^addr and data is being shifted into the STP modules from counter=1 onwards

## MRAM STP/PTS module standalone

MRAM is being written to on cycle 0 of the next loop

Therefore, writing takes 22 cycles (1 faster than the integrated module


^addr is fully inside the shift register at counter = 21.

## MRAM STP/PTS module standalone

Reading of data:

- Address needs to be provided first. Therefore, initial 21 cycles needed
- In the next loop, data gets serialy output from counter 3 onwards


^Data gets loaded in at counter = 2, shifted out at counter = 3

## MRAM STP/PTS module standalone

Reading of data:

- Subsequent reads in succession will case the loop to take 23 cycles due to shifting of data


^half word read, lower byte

## MRAM STP/PTS module standalone Summary

Writing:

- 22 cycles

Reading:

- Initial 22 cycles for writing address
- Subsequent 23 cycle per loop (due to shifting of data into registers I believe)
- Data is output on the next loop, cycle 3 to 18

## Questions n stuff

- Can I clarify, how does my memory controller fit into the PULP microprocessor? Does it act something like a shared memory between the PULP and accelerator that Yan Rui(the other FYP student) is developing?
- How can I request for the Zboard FPGA? Do I have to email Jeremiah for it?
- I only managed to finish this integration as there were quite a bit of bugs and synchronization issues between the 2 modules. I will continue to work on the other design I have in mind over the next few weeks.

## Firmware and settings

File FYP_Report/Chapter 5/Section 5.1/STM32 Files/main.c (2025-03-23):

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
/* Includes ------------------------------------------------------------------*/
#include "main.h"

TIM_HandleTypeDef htim1;
TIM_HandleTypeDef htim2;

UART_HandleTypeDef huart2;

void SystemClock_Config(void);
static void MX_GPIO_Init(void);
static void MX_USART2_UART_Init(void);
static void MX_TIM1_Init(void);
static void MX_TIM2_Init(void);
/**
  * @brief  The application entry point.
  * @retval int
  */
int main(void)
{
  /* MCU Configuration--------------------------------------------------------*/

  /* Reset of all peripherals, Initializes the Flash interface and the Systick. */
  HAL_Init();

  /* Configure the system clock */
  SystemClock_Config();

  /* Initialize all configured peripherals */
  MX_GPIO_Init();
  MX_USART2_UART_Init();
  MX_TIM1_Init();
  MX_TIM2_Init();
  /* USER CODE BEGIN 2 */
  	// Measuring Elapsed time
    uint32_t start, stop, elapsed;
    double elapsed_time;

	// Printing to terminal
	uint8_t tx_buff[64];
	int read_data[16];

	sprintf(tx_buff, "Starting Program\r\n");
	HAL_UART_Transmit(&huart2, tx_buff, 19, 1000);

	// Delay function
	HAL_TIM_Base_Start(&htim1);
	void delay_us (uint16_t us)
	{
	// Changes depending on prescaler set in TIM1.
	// TIM1 is connected to APB2 and will be clocked at 84Mhz
	// Possible to tweak the prescalar in order to change the clock speed
    // As of now, the prescaler is set to 1, meaning that the period is 1/84^6, approx 12ns.
	__HAL_TIM_SET_COUNTER(&htim1,0);  // set the counter value a 0
	while (__HAL_TIM_GET_COUNTER(&htim1) < us);  // wait for the counter to reach the us input in the parameter
	}

	// System reset. Ends with clock being low. 9 8 6 5
	void MRAM_reset(){
	  HAL_GPIO_WritePin(GPIOC, clk_Pin, 0);				// PC9
	  HAL_GPIO_WritePin(GPIOC, rst_Pin, 1);				// PC8
	  HAL_GPIO_WritePin(GPIOB, burst_en_Pin, 0);		// PB8
	  HAL_GPIO_WritePin(GPIOC, mode_sel_Pin, 0);		// PC6
	  HAL_GPIO_WritePin(GPIOB, burst_len_in_Pin, 0);	// PB9
	  HAL_GPIO_WritePin(GPIOC, addr_in_Pin, 0);			// PC5
	  HAL_GPIO_WritePin(GPIOA, data_in_Pin, 0);			// PA6
	  HAL_GPIO_WritePin(GPIOA, rws_0_Pin, 1);			// PA11
	  HAL_GPIO_WritePin(GPIOA, rws_1_Pin, 1);			// PA7
	  HAL_GPIO_WritePin(GPIOB, rws_2_Pin, 1);			// PB12
	  delay_us(1);
	  HAL_GPIO_WritePin(GPIOC, clk_Pin, 1);
	  delay_us(1);
	  HAL_GPIO_WritePin(GPIOC, clk_Pin, 0);
	}

	void MRAM_reset_no_HAL(){
		  // Set the GPIO pins
		  GPIOA->BSRR = 0x000008C0;
		  GPIOB->BSRR = 0x00001300;
		  GPIOC->BSRR = 0x00000360;

		  // Write the following values to the pins (as per MRAM_reset)
		  GPIOA->ODR = 0x00000880;
		  GPIOB->ODR = 0x00001000;
		  GPIOC->ODR = 0x00000100;
		  delay_us(1);
		  // Set clock high
		  GPIOC->ODR = 0x00000300;
		  delay_us(1);
		  // Set clock low
		  GPIOC->ODR = 0x00000100;
	}

	// Single word write
	uint32_t bitwise_one = 1;

	void MRAM_single_word_write(uint32_t addr_in, uint32_t data_in){		// 16-bit unsigned short
	  int  i;
	  uint32_t addr = addr_in;
	  uint32_t data = data_in;


	  for (i = 0; i < 23; i++){
		  HAL_GPIO_WritePin(GPIOC, clk_Pin, 0);					// PC9
		  HAL_GPIO_WritePin(GPIOC, rst_Pin, 0);					// PC8

		  if (i == 0){
			  HAL_GPIO_WritePin(GPIOB, burst_en_Pin, 0);		// PB8
			  HAL_GPIO_WritePin(GPIOC, mode_sel_Pin, 0);		// PC6
			  HAL_GPIO_WritePin(GPIOB, burst_len_in_Pin, 0);	// PB9
			  HAL_GPIO_WritePin(GPIOA, rws_0_Pin, 1);			// PA11
			  HAL_GPIO_WritePin(GPIOA, rws_1_Pin, 1);			// PA7
			  HAL_GPIO_WritePin(GPIOB, rws_2_Pin, 1);			// PB12
		  }
		  else{
			  if (i > 1){
				  addr = addr >> 1;
				  data = data >> 1;
			  }
			  HAL_GPIO_WritePin(GPIOC, addr_in_Pin, addr & bitwise_one);		// PC5
			  HAL_GPIO_WritePin(GPIOA, data_in_Pin, data & bitwise_one);		// PA6
		  }

		  //delay_us(1);
		  HAL_GPIO_WritePin(GPIOC, clk_Pin, 1);
		  //delay_us(1);
	  }
	}

	  void MRAM_single_word_write_no_HAL(uint32_t addr_in, uint32_t data_in){
	  	  int  i;
	  	  uint32_t addr = addr_in;
	  	  uint32_t data = data_in;


	  	  for (i = 0; i < 23; i++){
	  		  // Set clk and rst low
	  		  GPIOC->ODR = GPIOC->ODR & 0xFCFF;

	  		  if (i == 0){
	  			GPIOA->ODR = 0x00000880;
	  			GPIOB->ODR = 0x00001300;
	  			//GPIOC->ODR = 0x00000000;
	  		  }
	  		  else{
	  			  if (i > 1){
	  				  addr = addr >> 1;
	  				  data = data >> 1;
	  			  }
	  			  GPIOC->ODR = (GPIOC->ODR & 0xFFDF) | ((addr & bitwise_one) << 5);
	  			  GPIOA->ODR = (GPIOA->ODR & 0xFFBF) | ((data & bitwise_one) << 6);
	  		  }

	  		  //delay_us(1);
	  		  GPIOC->ODR = GPIOC->ODR | 0x200;
	  		  //delay_us(1);
	  	  }

	  // End on low clock
	  	GPIOC->ODR = 0x00000000;
	}

  	  // Single Word Read
  	  void MRAM_single_word_read(uint32_t addr_in, uint16_t arr_read[]){		// 16-bit unsigned short
  	  int  i;
  	  uint32_t addr = addr_in;
  	  uint16_t data = 0;

  	  // First loop to receive base address
  	  for (i = 0; i < 23; i++){
  		  HAL_GPIO_WritePin(GPIOC, clk_Pin, 0);
  		  HAL_GPIO_WritePin(GPIOC, rst_Pin, 0);

  		  if (i == 0){
  			  HAL_GPIO_WritePin(GPIOB, burst_en_Pin, 0);
  			  HAL_GPIO_WritePin(GPIOC, mode_sel_Pin, 0);
  			  HAL_GPIO_WritePin(GPIOB, burst_len_in_Pin, 0);
  			  HAL_GPIO_WritePin(GPIOA, rws_0_Pin, 0);
  			  HAL_GPIO_WritePin(GPIOA, rws_1_Pin, 1);
  			  HAL_GPIO_WritePin(GPIOB, rws_2_Pin, 1);
  		  }
  		  else{
  			if (i > 1){
  				addr = addr >> 1;
  			}
  			HAL_GPIO_WritePin(GPIOC, addr_in_Pin, addr & bitwise_one);
  		  }
  		  //delay_us(1);
  		  HAL_GPIO_WritePin(GPIOC, clk_Pin, 1);
  		  //delay_us(1);
  	  }

  	  // Second loop: Stall and receive data
  	    for (int i = 0; i < 2; i++){
  	    	  HAL_GPIO_WritePin(GPIOC, clk_Pin, 1);
  	    	  //delay_us(1);
  	    	  HAL_GPIO_WritePin(GPIOC, clk_Pin, 0);
  	    	  //delay_us(1);
  	    }

  	    for (int i = 0; i < 16; i++){
  	  	  HAL_GPIO_WritePin(GPIOC, clk_Pin, 1);
  	  	  //read_data[i] = HAL_GPIO_ReadPin(GPIOB, PTS_ser_out_Pin);								// PB6
  	  	  arr_read[0] = (arr_read[0] >> 1) | (HAL_GPIO_ReadPin(GPIOB, PTS_ser_out_Pin) << 15);
  	  	  //sprintf(tx_buff, "Data[%d]: %d \r\n", i, read_data[i]);
  	  	  //HAL_UART_Transmit(&huart2, tx_buff, 14, 1000);
  	  	  //delay_us(1);
  	  	  HAL_GPIO_WritePin(GPIOC, clk_Pin, 0);
  	  	  //delay_us(1);
  	    }

  	    //sprintf(tx_buff, "Data: %d%d%d%d%d%d%d%d%d%d%d%d%d%d%d%d \r\n", read_data[15], read_data[14], read_data[13], read_data[12], read_data[11], read_data[10], read_data[9], read_data[8], read_data[7], read_data[6], read_data[5], read_data[4], read_data[3], read_data[2], read_data[1], read_data[0]);
  	    //HAL_UART_Transmit(&huart2, tx_buff, 27, 1000);
  	    //sprintf(tx_buff, "Data: %x\r\n", data);
  	  	//HAL_UART_Transmit(&huart2, tx_buff, 27, 1000);

  	    // End on low clock
  	    HAL_GPIO_WritePin(GPIOC, clk_Pin, 0);
    }

  	void MRAM_single_word_read_no_HAL(uint32_t addr_in, uint16_t arr_read[]){
		  int  i;
		  uint32_t addr = addr_in;
		  uint16_t data = 0;

		  for (i = 0; i < 23; i++){
			  // Set clk and rst low
			  GPIOC->ODR = GPIOC->ODR & 0xFCFF;

			  if (i == 0){
				GPIOA->ODR = 0x00000080;
				GPIOB->ODR = 0x00001300;		// should be 0x00001000
				//GPIOC->ODR = 0x00000000;
			  }
			  else{
				  if (i > 1){
					  addr = addr >> 1;
				  }
				  // Shift in the bits from LSB to MSB
				  GPIOC->ODR = (GPIOC->ODR & 0xFFDF) | ((addr & bitwise_one) << 5);
			  }

			  //delay_us(1);
			  GPIOC->ODR = GPIOC->ODR | 0x200;
			  //delay_us(1);
		  }

		// Second loop: Stall and receive data
		for (int i = 0; i < 2; i++){
			  GPIOC->ODR = GPIOC->ODR | 0x200;
			  //delay_us(1);
			  GPIOC->ODR = GPIOC->ODR & 0xFCFF;
			  //delay_us(1);
		}

		for (int i = 0; i < 16; i++){
		  GPIOC->ODR = GPIOC->ODR | 0x200;
		  arr_read[0] = arr_read[0] >> 1 | ((GPIOB->IDR & 0x40) << 9);
		  //delay_us(1);
		  GPIOC->ODR = GPIOC->ODR & 0xFCFF;
		  //delay_us(1);
		}

		// End on low clock
		GPIOC->ODR = GPIOC->ODR & 0xFCFF;
	}


  	// Burst write
  	void MRAM_burst_write(uint32_t addr_in, uint32_t data_arr[], uint32_t burst_len_in){
  		int i;
  		int j;
  		uint32_t addr = addr_in;
  		uint32_t burst_len = burst_len_in;		// Burst_len has same len as array len
  		uint32_t burst_len_loop = burst_len_in;
  		uint32_t data;

  		for (i = 0; i < burst_len_loop; i++ ){

  			data = data_arr[i];

  			for (j = 0; j < 23; j++){
				  HAL_GPIO_WritePin(GPIOC, clk_Pin, 0);
				  HAL_GPIO_WritePin(GPIOC, rst_Pin, 0);

				  if (j == 0){
					  HAL_GPIO_WritePin(GPIOB, burst_en_Pin, 1);
					  HAL_GPIO_WritePin(GPIOC, mode_sel_Pin, 1);
					  HAL_GPIO_WritePin(GPIOA, rws_0_Pin, 1);
					  HAL_GPIO_WritePin(GPIOA, rws_1_Pin, 1);
					  HAL_GPIO_WritePin(GPIOB, rws_2_Pin, 1);
				  }
				  else{
					  if (j > 1){
						  addr = addr >> 1;
						  data = data >> 1;
						  burst_len = burst_len >> 1;
					  }
					  HAL_GPIO_WritePin(GPIOC, addr_in_Pin, addr & bitwise_one);
					  HAL_GPIO_WritePin(GPIOA, data_in_Pin, data & bitwise_one);
					  HAL_GPIO_WritePin(GPIOB, burst_len_in_Pin, burst_len & bitwise_one);
				  }

				  //delay_us(1);
				  HAL_GPIO_WritePin(GPIOC, clk_Pin, 1);
				  //delay_us(1);
  			}
  		}
  		// End on low clock
  		HAL_GPIO_WritePin(GPIOC, clk_Pin, 0);
  	}

  	// Burst write
  	  	void MRAM_burst_write_no_HAL(uint32_t addr_in, uint32_t data_arr[], uint32_t burst_len_in){
  	  		int i;
  	  		int j;
  	  		uint32_t addr = addr_in;
  	  		uint32_t burst_len = burst_len_in;		// Burst_len has same len as array len
  	  		uint32_t burst_len_loop = burst_len_in;
  	  		uint32_t data;

  	  		for (i = 0; i < burst_len_loop; i++ ){

  	  			data = data_arr[i];

  	  			for (j = 0; j < 23; j++){

  	  				  GPIOC->ODR = GPIOC->ODR & 0xFCFF;

  					  if (j == 0){
  						  GPIOA->ODR = GPIOA->ODR | 0x00000880;
  						  GPIOB->ODR = GPIOA->ODR | 0x00001100;
  						  GPIOC->ODR = GPIOA->ODR | 0x00000040;
  					  }
  					  else{
  						  if (j > 1){
  							  addr = addr >> 1;
  							  data = data >> 1;
  							  burst_len = burst_len >> 1;
  						  }
  						  GPIOC->ODR = (GPIOC->ODR & 0xFFDF) | ((addr & bitwise_one) << 5);
  						  GPIOA->ODR = (GPIOA->ODR & 0xFFBF) | ((data & bitwise_one) << 6);
  						  GPIOB->ODR = (GPIOB->ODR & 0xFDFF) | ((burst_len & bitwise_one) << 9);
  					  }

  					  //delay_us(1);
  					  GPIOC->ODR = GPIOC->ODR | 0x200;
  					  //delay_us(1);
  	  			}
  	  		}
  	  		// End on low clock
  	  		GPIOC->ODR = GPIOC->ODR & 0xFCFF;
  	  	}

  	// Burst read
  	void MRAM_burst_read(uint32_t addr_in, uint16_t arr_read[], uint32_t burst_len_in){
  		int i;
  		int j;
  		uint32_t addr = addr_in;
  		uint32_t burst_len = burst_len_in;
  		uint32_t burst_len_loop = burst_len_in;
  		uint16_t data = 0;

  		for (i = 0; i <= burst_len_loop; i++){
  			switch(i){
  			case 0:
  				for (j = 0; j < 23; j++){
  					HAL_GPIO_WritePin(GPIOC, clk_Pin, 0);
  					HAL_GPIO_WritePin(GPIOC, rst_Pin, 0);
					if (j == 0){
						  HAL_GPIO_WritePin(GPIOB, burst_en_Pin, 1);
						  HAL_GPIO_WritePin(GPIOC, mode_sel_Pin, 1);
						  HAL_GPIO_WritePin(GPIOA, rws_0_Pin, 0);
						  HAL_GPIO_WritePin(GPIOA, rws_1_Pin, 1);
						  HAL_GPIO_WritePin(GPIOB, rws_2_Pin, 1);
					}
					else{
						if (j > 1){
							  addr = addr >> 1;
							  burst_len = burst_len >> 1;
						  }
						  HAL_GPIO_WritePin(GPIOC, addr_in_Pin, addr & bitwise_one);
						  HAL_GPIO_WritePin(GPIOB, burst_len_in_Pin, burst_len & bitwise_one);
					}
					//delay_us(1);
				    HAL_GPIO_WritePin(GPIOC, clk_Pin, 1);
				    //delay_us(1);
				}
  				break;

  			default:
  				for (int k = 0; k < 1; k++){
  					  HAL_GPIO_WritePin(GPIOC, clk_Pin, 0);
  					  //delay_us(1);
					  HAL_GPIO_WritePin(GPIOC, clk_Pin, 1);
					  //delay_us(1);
				}
  				for (int k = 0; k < 16; k++){
  					  HAL_GPIO_WritePin(GPIOC, clk_Pin, 0);
  					  //delay_us(1);
					  HAL_GPIO_WritePin(GPIOC, clk_Pin, 1);
					  //read_data[k] = HAL_GPIO_ReadPin(GPIOB, PTS_ser_out_Pin);
					  arr_read[i-1] = (arr_read[i-1] >> 1) | (HAL_GPIO_ReadPin(GPIOB, PTS_ser_out_Pin) << 15);
					  //sprintf(tx_buff, "Data[%d]: %d \r\n", k, read_data[k]);
					  //HAL_UART_Transmit(&huart2, tx_buff, 14, 1000);
					  //delay_us(1);
				}

				//sprintf(tx_buff, "Data: %d%d%d%d%d%d%d%d%d%d%d%d%d%d%d%d \r\n", read_data[15], read_data[14], read_data[13], read_data[12], read_data[11], read_data[10], read_data[9], read_data[8], read_data[7], read_data[6], read_data[5], read_data[4], read_data[3], read_data[2], read_data[1], read_data[0]);
				//HAL_UART_Transmit(&huart2, tx_buff, 27, 1000);
				//sprintf(tx_buff, "Data: %x\r\n", data);
				//HAL_UART_Transmit(&huart2, tx_buff, 27, 1000);

				for (int k = 0; k < 6; k++){
					HAL_GPIO_WritePin(GPIOC, clk_Pin, 0);
					//delay_us(1);
				    HAL_GPIO_WritePin(GPIOC, clk_Pin, 1);
				    //delay_us(1);
				}
				break;
  			}

  		}
  		// End on low clock
  		HAL_GPIO_WritePin(GPIOC, clk_Pin, 0);
  	}

  	// Burst read
	void MRAM_burst_read_no_HAL(uint32_t addr_in, uint16_t arr_read[], uint32_t burst_len_in){
		int i;
		int j;
		uint32_t addr = addr_in;
		uint32_t burst_len = burst_len_in;
		uint32_t burst_len_loop = burst_len_in;

		for (i = 0; i <= burst_len_loop; i++){
			switch(i){
			case 0:
				for (j = 0; j < 23; j++){

					GPIOC->ODR = GPIOC->ODR & 0xFCFF;

					if (j == 0){
						GPIOA->ODR = 0x00000080;
					    GPIOB->ODR = 0x00001300;
					    GPIOC->ODR = GPIOC->ODR | 0x00000040;
					}
					else{
						if (j > 1){
							  addr = addr >> 1;
							  burst_len = burst_len >> 1;
						  }
						GPIOC->ODR = (GPIOC->ODR & 0xFFDF) | ((addr & bitwise_one) << 5);
					    GPIOB->ODR = (GPIOB->ODR & 0xFDFF) | ((burst_len & bitwise_one) << 9);
					}
					//delay_us(1);
					GPIOC->ODR = GPIOC->ODR | 0x200;
					//delay_us(1);
				}
				break;

			default:
				for (int k = 0; k < 1; k++){
					GPIOC->ODR = GPIOC->ODR & 0xFCFF;
				    //delay_us(1);
				    GPIOC->ODR = GPIOC->ODR | 0x200;
				    //delay_us(1);
				}
				for (int k = 0; k < 16; k++){
					  GPIOC->ODR = GPIOC->ODR & 0xFCFF;
					  //delay_us(1);
					  GPIOC->ODR = GPIOC->ODR | 0x200;
					  arr_read[i-1] = (arr_read[i-1] >> 1) | (HAL_GPIO_ReadPin(GPIOB, PTS_ser_out_Pin) << 15);
					  //delay_us(1);
				}

				for (int k = 0; k < 6; k++){
					GPIOC->ODR = GPIOC->ODR & 0xFCFF;
					//delay_us(1);
					GPIOC->ODR = GPIOC->ODR | 0x200;
					//delay_us(1);
				}
				break;
			}

		}
		// End on low clock
		GPIOC->ODR = GPIOC->ODR & 0xFCFF;
	}


  /* USER CODE END 2 */

  /* Infinite loop */
  /* USER CODE BEGIN WHILE */
  uint32_t arr[] = {0x89ab, 0x5555, 0x1234};
  //uint32_t arr[] = {0x1234, 0x5678, 0x9abc};
  uint32_t arr_8B[] = {0x1234, 0x5678, 0x9abc, 0xdef0};
  uint32_t arr_16B[] = {0x4321, 0x8765, 0xcba9, 0x0fed, 0x1111, 0x2222, 0x3333, 0x4444};
  uint32_t arr_32B[] = {0x1122, 0x3344, 0x4455, 0x6677, 0x8899, 0xaabb, 0xccdd, 0xeeff, 0x1234, 0x5678, 0x9abc, 0xdef0, 0x4321, 0x8765, 0xcba9, 0x0fed};
  //uint32_t arr_32B[] = {0x3344, 0x4455, 0x6677, 0x8899, 0xaabb, 0xccdd, 0xeeff, 0x1234, 0x5678, 0x9abc, 0xdef0, 0x4321, 0x8765, 0xcba9, 0x0fed, 0x1122};
  uint16_t arr_read[16];
  GPIOA->BSRR = 0x00000400;
  GPIOB->BSRR = 0x00000400;
  GPIOC->BSRR = 0x00000400;

  __HAL_RCC_TIM2_CLK_ENABLE();
  //TIM2->PSC = HAL_RCC_GetPCLK1Freq()/1000000 - 1;
  TIM2->CR1 = TIM_CR1_CEN;
  while (1)
  {
    /* USER CODE END WHILE */

    /* USER CODE BEGIN 3 */
	  // Timer 2's counter
	  //__HAL_TIM_SET_COUNTER(&htim2,0);  // set the counter value a 0
	  //start = TIM2->CNT;

	  // MRAM operation
	  MRAM_reset();
	  //MRAM_reset_no_HAL();
	  //start = TIM2->CNT;
	  //MRAM_single_word_write(0, 0x4567);
	  //MRAM_single_word_write_no_HAL(0, 0xabcd);
	  //for (int c = 0; c < 4; c++){
		  //MRAM_single_word_write(c, arr_8B[c]);
	  //}
	  //stop = TIM2->CNT;

	  start = TIM2->CNT;
	  //MRAM_single_word_read(0, arr_read);
	  MRAM_single_word_read_no_HAL(0, arr_read);
	  //for (int c = 0; c < 4; c++){
	  //		  MRAM_single_word_read(c, arr_read[c]);
	  //}
	  stop = TIM2->CNT;

	  //MRAM_burst_read_no_HAL(0, arr_read, 4);


	  //start = TIM2->CNT;
	  //MRAM_burst_write(0, arr_8B, 4);
	  //MRAM_burst_write_no_HAL(0, arr_8B, 4);
	  //stop = TIM2->CNT;
	  //MRAM_reset();

	  //start = TIM2->CNT;
	  //MRAM_burst_read(0, arr_read, 4);
	  //MRAM_burst_read_no_HAL(0, arr_read, 4);
	  //stop = TIM2->CNT;

	  //MRAM_reset();
	  //MRAM_single_word_read(2);

	  // Stop counter, read the time
	  //stop = TIM2->CNT;
	  elapsed = stop - start;
	  elapsed_time = elapsed;
	  sprintf(tx_buff, "Elapsed Time: %d us\r\n", elapsed);
	  HAL_UART_Transmit(&huart2, tx_buff, 23, 1000);


	  for (int b = 0; b < 1; b++){
		  sprintf(tx_buff, "Data: 0x%x \r\n", arr_read[b]);
		  HAL_UART_Transmit(&huart2, tx_buff, 16, 1000);
	  }


	  //sprintf(tx_buff, "Data: 0x%x \r\n", arr_read[0]);
	  //HAL_UART_Transmit(&huart2, tx_buff, 16, 1000);

	  /*
	  // Testing GPIO manipulation without HAL
	  // Set the gpio pin
	  GPIOA->BSRR = 0x00000020;
	  // Set output of gpio pin to 1
	  GPIOA->ODR = 0x00000020;
	  HAL_Delay(1000);
	  // Set output of gpio pin to 1
	  GPIOA->ODR = 0x00000000;
	  HAL_Delay(1000);
	*/


	  //HAL_GPIO_TogglePin(GPIOC, GPIO_PIN_10);
	  //GPIOC->ODR = 0x400;
	  //delay_us(1);
	  //GPIOC->ODR = 0x000;
	  //delay_us(1);

	  while (1){
		  HAL_Delay(1000);
	  }
  }
  /* USER CODE END 3 */
}

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


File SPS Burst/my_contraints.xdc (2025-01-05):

# Connected to Addr pins of MRAM
set_property PACKAGE_PIN A21 [get_ports {addr_to_MRAM[0]}];  # "FMC-LA32_P"
set_property PACKAGE_PIN A22 [get_ports {addr_to_MRAM[1]}];  # "FMC-LA32_N"
set_property PACKAGE_PIN C15 [get_ports {addr_to_MRAM[2]}];  # "FMC-LA30_P"
set_property PACKAGE_PIN B15 [get_ports {addr_to_MRAM[3]}];  # "FMC-LA30_N"
set_property PACKAGE_PIN A16 [get_ports {addr_to_MRAM[4]}];  # "FMC-LA28_P"
set_property PACKAGE_PIN A17 [get_ports {addr_to_MRAM[5]}];  # "FMC-LA28_N"
set_property PACKAGE_PIN A18 [get_ports {addr_to_MRAM[6]}];  # "FMC-LA24_P"
set_property PACKAGE_PIN A19 [get_ports {addr_to_MRAM[7]}];  # "FMC-LA24_N"
set_property PACKAGE_PIN E19 [get_ports {addr_to_MRAM[8]}];  # "FMC-LA21_P"
set_property PACKAGE_PIN E20 [get_ports {addr_to_MRAM[9]}];  # "FMC-LA21_N"
set_property PACKAGE_PIN G15 [get_ports {addr_to_MRAM[10]}];  # "FMC-LA19_P"
set_property PACKAGE_PIN G16 [get_ports {addr_to_MRAM[11]}];  # "FMC-LA19_N"
set_property PACKAGE_PIN J16 [get_ports {addr_to_MRAM[12]}];  # "FMC-LA15_P"
set_property PACKAGE_PIN J17 [get_ports {addr_to_MRAM[13]}];  # "FMC-LA15_N"
set_property PACKAGE_PIN N17 [get_ports {addr_to_MRAM[14]}];  # "FMC-LA11_P"
set_property PACKAGE_PIN N18 [get_ports {addr_to_MRAM[15]}];  # "FMC-LA11_N"
set_property PACKAGE_PIN T16 [get_ports {addr_to_MRAM[16]}];  # "FMC-LA07_P"
set_property PACKAGE_PIN T17 [get_ports {addr_to_MRAM[17]}];  # "FMC-LA07_N"
set_property PACKAGE_PIN M21 [get_ports {addr_to_MRAM[18]}];  # "FMC-LA04_P"
set_property PACKAGE_PIN M22 [get_ports {addr_to_MRAM[19]}];  # "FMC-LA04_N"


# Connected to Data pins of MRAM
set_property PACKAGE_PIN C18 [get_ports {data_to_MRAM[0]}];  # "FMC-LA29_N"
set_property PACKAGE_PIN C17 [get_ports {data_to_MRAM[1]}];  # "FMC-LA29_P"
set_property PACKAGE_PIN C22 [get_ports {data_to_MRAM[2]}];  # "FMC-LA25_N"
set_property PACKAGE_PIN D22 [get_ports {data_to_MRAM[3]}];  # "FMC-LA25_P"
set_property PACKAGE_PIN F19 [get_ports {data_to_MRAM[4]}];  # "FMC-LA22_N"
set_property PACKAGE_PIN G19 [get_ports {data_to_MRAM[5]}];  # "FMC-LA22_P"
set_property PACKAGE_PIN G21 [get_ports {data_to_MRAM[6]}];  # "FMC-LA20_N"
set_property PACKAGE_PIN G20 [get_ports {data_to_MRAM[7]}];  # "FMC-LA20_P"
set_property PACKAGE_PIN K21 [get_ports {data_to_MRAM[8]}];  # "FMC-LA16_N"
set_property PACKAGE_PIN J20 [get_ports {data_to_MRAM[9]}];  # "FMC-LA16_P"
set_property PACKAGE_PIN P21 [get_ports {data_to_MRAM[10]}];  # "FMC-LA12_N"
set_property PACKAGE_PIN P20 [get_ports {data_to_MRAM[11]}];  # "FMC-LA12_P"
set_property PACKAGE_PIN J22 [get_ports {data_to_MRAM[12]}];  # "FMC-LA08_N"
set_property PACKAGE_PIN J21 [get_ports {data_to_MRAM[13]}];  # "FMC-LA08_P"
set_property PACKAGE_PIN P22 [get_ports {data_to_MRAM[14]}];  # "FMC-LA03_N"
set_property PACKAGE_PIN N22 [get_ports {data_to_MRAM[15]}];  # "FMC-LA03_P"

# Connected to control signals of MRAM
set_property PACKAGE_PIN P17 [get_ports {chip_en}];         # "FMC-LA02_P"
set_property PACKAGE_PIN B22 [get_ports {out_en}];          # "FMC-LA33_N"
set_property PACKAGE_PIN B21 [get_ports {write_en}];        # "FMC-LA33_P"
set_property PACKAGE_PIN B17 [get_ports {lower_byte_en}];   # "FMC-LA31_N"
set_property PACKAGE_PIN B16 [get_ports {upper_byte_en}];   # "FMC-LA31_P"


# SPS burst module IO pins
set_property PACKAGE_PIN J18 [get_ports {clk}];             # "FMC-LA05_P"
set_property PACKAGE_PIN K18 [get_ports {rst}];             # "FMC-LA05_N"
set_property PACKAGE_PIN L21 [get_ports {burst_en}];        # "FMC-LA06_P"
set_property PACKAGE_PIN L22 [get_ports {mode_sel}];        # "FMC-LA06_N"
set_property PACKAGE_PIN R20 [get_ports {burst_len_in}];    # "FMC-LA09_P"
set_property PACKAGE_PIN R21 [get_ports {addr_in}];         # "FMC-LA09_N"
set_property PACKAGE_PIN R19 [get_ports {data_in}];         # "FMC-LA10_P"
set_property PACKAGE_PIN T19 [get_ports {read_write_sel[0]}];   # "FMC-LA10_N"
set_property PACKAGE_PIN L17 [get_ports {read_write_sel[1]}];  # "FMC-LA13_P"
set_property PACKAGE_PIN M17 [get_ports {read_write_sel[2]}];  # "FMC-LA13_N"
set_property PACKAGE_PIN K19 [get_ports {PTS_ser_data_out}];  # "FMC-LA14_P"

# GPIO
set_property PACKAGE_PIN K20 [get_ports {gpio_rtl_0_tri_io[0]}];  # "FMC-LA14_N"
set_property PACKAGE_PIN B19 [get_ports {gpio_rtl_tri_io[0]}];  # "FMC-LA17_CC_P"
set_property PACKAGE_PIN B20 [get_ports {gpio_rtl_tri_io[1]}];  # "FMC-LA17_CC_N"
set_property PACKAGE_PIN D20 [get_ports {gpio_rtl_tri_io[2]}];  # "FMC-LA18_CC_P"
set_property PACKAGE_PIN C20 [get_ports {gpio_rtl_tri_io[3]}];  # "FMC-LA18_CC_N"
set_property PACKAGE_PIN E15 [get_ports {gpio_rtl_tri_io[4]}];  # "FMC-LA23_P"
set_property PACKAGE_PIN D15 [get_ports {gpio_rtl_tri_io[5]}];  # "FMC-LA23_N"
set_property PACKAGE_PIN F18 [get_ports {gpio_rtl_tri_io[6]}];  # "FMC-LA26_P"
set_property PACKAGE_PIN E18 [get_ports {gpio_rtl_tri_io[7]}];  # "FMC-LA26_N"
set_property PACKAGE_PIN E21 [get_ports {gpio_rtl_tri_io[8]}];  # "FMC-LA27_P"
set_property PACKAGE_PIN D21 [get_ports {gpio_rtl_tri_io[9]}];  # "FMC-LA27_N"
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

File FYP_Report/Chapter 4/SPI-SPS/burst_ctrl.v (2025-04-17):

`timescale 1ns / 1ps
//////////////////////////////////////////////////////////////////////////////////
// Company: 
// Engineer: 
// 
// Create Date: 04.10.2024 00:39:56
// Design Name: 
// Module Name: burst_ctrl
// Project Name: 
// Target Devices: 
// Tool Versions: 
// Description: 
// 
// Dependencies: 
// 
// Revision:
// Revision 0.01 - File Created
// Additional Comments:
// 
//////////////////////////////////////////////////////////////////////////////////


module burst_ctrl(
    input clk,
    input rst,
    
    // Burst Mode Signals
    input en,                       // Enables the burst control module
    input mode_sel,                 // 0 -> Single Transfer, 1-> Burst Mode


    // burst_len_STP Signals
    output reg burst_len_en,
    output reg send_burst_len_data,
    
    
    // addr_STP signals
    output reg initial_addr_en,
    output reg send_addr_data,
    
    
    //  addr_PTS_out signals
    output reg addr_PTS_out_rst,
    output reg addr_PTS_out_en,
    output reg addr_PTS_out_load,
    output reg addr_PTS_out_send_data,
    output reg [1:0] addr_PTS_out_word_sel,
    
    
    // counter signals
    input stop_signal,
    output reg counter_en,
    
    
    // adder signals
    output reg adder_en,
    
    
    // Mux Signal
    output reg addr_sel
);

// Flag to determine if the initial burst len and addr is loaded into the register
// 0 -> Not loaded in | 1 -> Loaded in.
reg addr_loaded_flag;       

// 6-bit counter to keep track of the number of clock cycles
reg [5:0] internal_counter;

always @(posedge clk or posedge rst)
begin
    if (rst) begin
        // burst_len_STP Signals
        burst_len_en <= 0;
        send_burst_len_data <= 0;
        
        
        // addr_STP signals
        initial_addr_en <= 0;
        send_addr_data <= 0;
        
        
        //  addr_PTS_out signals
        addr_PTS_out_rst <= 0;
        addr_PTS_out_en <= 0;
        addr_PTS_out_load <= 0;
        addr_PTS_out_send_data <= 0;
        addr_PTS_out_word_sel <= 0; 
        
        
        // counter signals
        counter_en <= 0;
        
        
        // adder signals
        adder_en <= 0;
        
        
        // Mux Signal
        addr_sel <= 0;
        
        // Initialize flag to 0
        addr_loaded_flag <= 0;
        
        // Initialize counter to 0
        internal_counter <= 0;
        
    end
    else begin 
        if (en && ~mode_sel) begin
            // If mode_sel is 0, Single Transfer is selected. Set the mux input to 0 to use the serial addr in. No other signals are necesary
            addr_sel <= 0;
        end
        else if (en && stop_signal) begin
            addr_loaded_flag <= 0;
        end
        else if (en && mode_sel && ~stop_signal) begin
            // If mode_sel is 1, Burst Transfer is selected.
            
            // Assign new value as old value (prevent latches)
            burst_len_en <= burst_len_en;
            send_burst_len_data <= send_burst_len_data;
            
            initial_addr_en <= initial_addr_en;
            send_addr_data <= 0;
            
            addr_PTS_out_rst <= addr_PTS_out_rst;
            addr_PTS_out_en <= addr_PTS_out_en;
            addr_PTS_out_load <= addr_PTS_out_load;
            addr_PTS_out_send_data <= addr_PTS_out_send_data;
            addr_PTS_out_word_sel <= addr_PTS_out_word_sel; 

            counter_en <= counter_en;
            
            adder_en <= adder_en;
            
            addr_sel <= addr_sel;

            addr_loaded_flag <= addr_loaded_flag;
            
            case (internal_counter)
                6'd0:   begin
                        if (~addr_loaded_flag) begin
                            burst_len_en <= 1;          // Enable STP burst_len on the next clk cycle
                            initial_addr_en <= 1;       // Enable STP initial_addr_in on the next clk cycle
                        end
                        
                        else begin
                            addr_sel <= 1;
                            
                            addr_PTS_out_en <= 1;
                            addr_PTS_out_load <= 0;
                            addr_PTS_out_send_data <= 1;
                            addr_PTS_out_word_sel <= 2'b11;
                        end
                        
                        end
                /*        
                6'd1:   begin
                        counter_en <= 0;
                        adder_en <= 0;
                        end
                */       
                6'd5:   
                begin
                        if (~addr_loaded_flag) begin
                            burst_len_en <= 0;              // Disable STP burst_len on the next clk cycle
                            send_burst_len_data <= 1;       // Move the burst_len compare module
                        end
                        
                        end
                        
                6'd20:  begin
                        if (~addr_loaded_flag) begin
                            initial_addr_en <= 0;           // Disable STP initial_addr_en on the next clk cycle
                            send_addr_data <= 1;            // Move the burst_len into the adder module
                        end
                        
                        // Assert these signals early
                        counter_en <= 1;                    
                        adder_en <= 1;
                        
                        addr_PTS_out_en <= 0;
                        addr_PTS_out_load <= 0;
                        addr_PTS_out_send_data <= 0;
                        end
                        
                6'd21:  begin
                        if (~addr_loaded_flag) begin
                            addr_loaded_flag <= 1;                      // Burst_len and initial_addr has been loaded in. Stop the loading of data.
                        end
                        
                        counter_en <= 0; 
                        addr_PTS_out_rst <= 1;
                        end
                        
                6'd22:  begin
                        addr_PTS_out_rst <= 0;
                        addr_PTS_out_en <= 1;
                        addr_PTS_out_load <= 1;
                        addr_PTS_out_send_data <= 0;
                        end
                        
               
            endcase
            
            // These 2 are not occuring sequentially
            internal_counter <= internal_counter + 1;
            if (internal_counter == 22) internal_counter <= 0;
            
        end
    
    end

end

endmodule

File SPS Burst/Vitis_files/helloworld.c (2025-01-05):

/******************************************************************************
* Copyright (C) 2023 Advanced Micro Devices, Inc. All Rights Reserved.
* SPDX-License-Identifier: MIT
******************************************************************************/
/*
 * helloworld.c: simple test application
 *
 * This application configures UART 16550 to baud rate 9600.
 * PS7 UART (Zynq) is not initialized by this application, since
 * bootrom/bsp configures it to baud rate 115200
 *
 * ------------------------------------------------
 * | UART TYPE   BAUD RATE                        |
 * ------------------------------------------------
 *   uartns550   9600
 *   uartlite    Configurable only in HW design
 *   ps7_uart    115200 (configured by bootrom/bsp)
 */

#include <stdio.h>
#include "platform.h"
#include "xil_printf.h"

#include "xgpio.h"
#include "xparameters.h"
#include "stdio.h"
#include "sleep.h"

int main()
{
    XGpio GPIO_output;
    XGpio GPIO_input;
    unsigned int GPIO_value;
    unsigned int read_value;
    init_platform();

    print("Starting SPS burst\n\r");
    
    XGpio_Initialize(&GPIO_output, XPAR_AXI_GPIO_0_BASEADDR);
    XGpio_Initialize(&GPIO_input, XPAR_AXI_GPIO_1_BASEADDR);

    XGpio_SetDataDirection(&GPIO_output, 1, 0x000);
    XGpio_SetDataDirection(&GPIO_input, 1, 0x1);

    /* GPIO output in order:
    0 -> clk
    1 -> rst
    2 -> burst_en
    3 -> mode_sel
    4 -> burst_len_in
    5 -> addr_in
    6 -> data_in
    7 -> read_write_sel[0]
    8 -> read_write_sel[1]
    9 -> read_write_sel[2]

    GPIO input:
    PTS_ser_data_out
    */

//-----------------------BURST WRITE AT ADDR 0----------------------------------------------//
/*
    // Reset the module. 
    print("Starting burst write of length 3\n\r");
    GPIO_value = 0b1110000010;
    XGpio_DiscreteWrite(&GPIO_output, 1, GPIO_value);
    usleep(100);
    GPIO_value = 0b1110000011;
    XGpio_DiscreteWrite(&GPIO_output, 1, GPIO_value);
    usleep(100);

    // Cycle 0
    GPIO_value = 0b1111011101;      // Pull rst low
    GPIO_value = GPIO_value ^ 0b0000000001;         // toggle clock
    XGpio_DiscreteWrite(&GPIO_output, 1, GPIO_value);
    usleep(100);
    GPIO_value = GPIO_value ^ 0b0000000001;
    XGpio_DiscreteWrite(&GPIO_output, 1, GPIO_value);
    usleep(100);
    
    // Cycle 1, Set burst length to 3
    GPIO_value = 0b1110011101;      
    GPIO_value = GPIO_value ^ 0b0001000001;         // toggle clock
    XGpio_DiscreteWrite(&GPIO_output, 1, GPIO_value);
    usleep(100);
    GPIO_value = GPIO_value ^ 0b0000000001;
    XGpio_DiscreteWrite(&GPIO_output, 1, GPIO_value);
    usleep(100);

    // Cycle 2, Set burst length to 3
    GPIO_value = 0b1110011101;      
    GPIO_value = GPIO_value ^ 0b0001000001;         // toggle clock
    XGpio_DiscreteWrite(&GPIO_output, 1, GPIO_value);
    usleep(100);
    GPIO_value = GPIO_value ^ 0b0000000001;
    XGpio_DiscreteWrite(&GPIO_output, 1, GPIO_value);
    usleep(100);
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

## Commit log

2024-12-05 Create LED&DIP_constraints.xdc
    Exercise 4 of the Zedboard workshop pdf
2024-12-07 Update and rename Testing MRAM with STM32F411RE/MRAM.ioc to Testing MRAM with STM32F411RE/Direct_To_MRAM/MRAM.ioc
2024-12-07 Update and rename Testing MRAM with STM32F411RE/main.c to Testing MRAM with STM32F411RE/Direct_To_MRAM/main.c
2024-12-07 Update and rename Testing MRAM with STM32F411RE/STP_LED.ioc to Testing MRAM with STM32F411RE/Through_STP_Modue/STP_LED.ioc
2024-12-07 Update and rename Testing MRAM with STM32F411RE/main.c to Testing MRAM with STM32F411RE/Through_STP_Module/main.c
2024-12-09 Create main.c
    STM32 main.c file for testing SPS burst module on the Tang Nano 9k
2024-12-09 Update and rename Testing MRAM with STM32F411RE/SPS_Burst_Test/SPS_Burst.ioc to Testing MRAM with STM32F411RE/SPS_Burst_Test/STM32_files/SPS_Burst.ioc
2024-12-09 Rename Testing MRAM with STM32F411RE/SPS_Burst_Test/main.c to Testing MRAM with STM32F411RE/SPS_Burst_Test/STM32_files/main.c
2024-12-13 Rename I2C_Simple_Slave_Controller.v to I2C Single Data Line /Simple_Slave_Controller.v
2024-12-13 Update Simple_Slave_Controller.v
    First iteration of I2C module, not yet integrated with simulated MRAM yet
2024-12-14 Add files via upload
    Tests both burst read and burst write of the I2C implementation
2025-01-09 Rename I2C_Module (Tang Nano)/temp to I2C_Module (Tang Nano)/Verilog FIles/temp
2025-03-23 Create STM32 Files

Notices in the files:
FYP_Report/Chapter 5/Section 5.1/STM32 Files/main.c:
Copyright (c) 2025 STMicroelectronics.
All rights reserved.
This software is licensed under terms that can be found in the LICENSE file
